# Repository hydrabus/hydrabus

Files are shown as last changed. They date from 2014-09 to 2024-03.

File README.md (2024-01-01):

HydraBus
========

HydraBus an open source multi-tool hardware

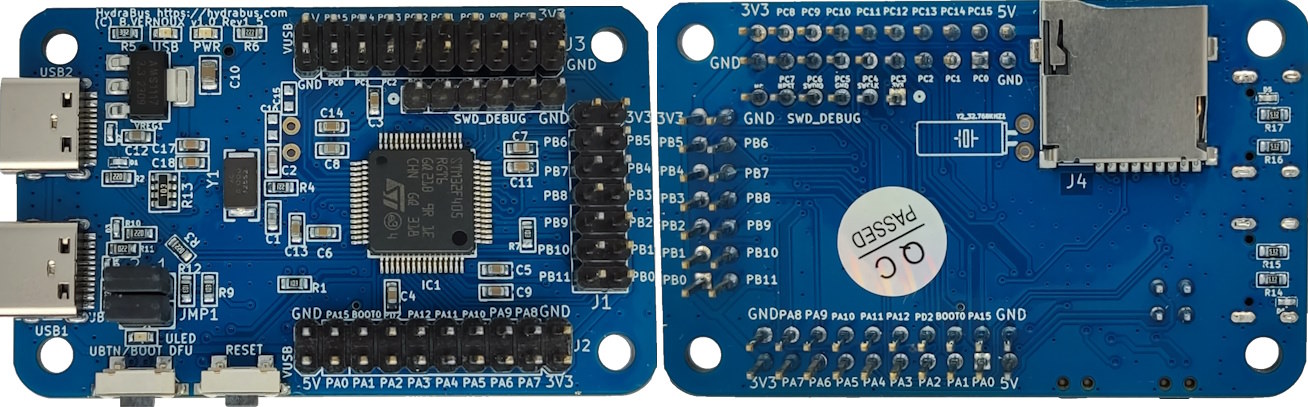
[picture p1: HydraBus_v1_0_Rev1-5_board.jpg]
HydraBus v1.0 Rev1.5 board


You can Buy HydraBus/HydraNFC Online: http://hydrabus.com/buy-online

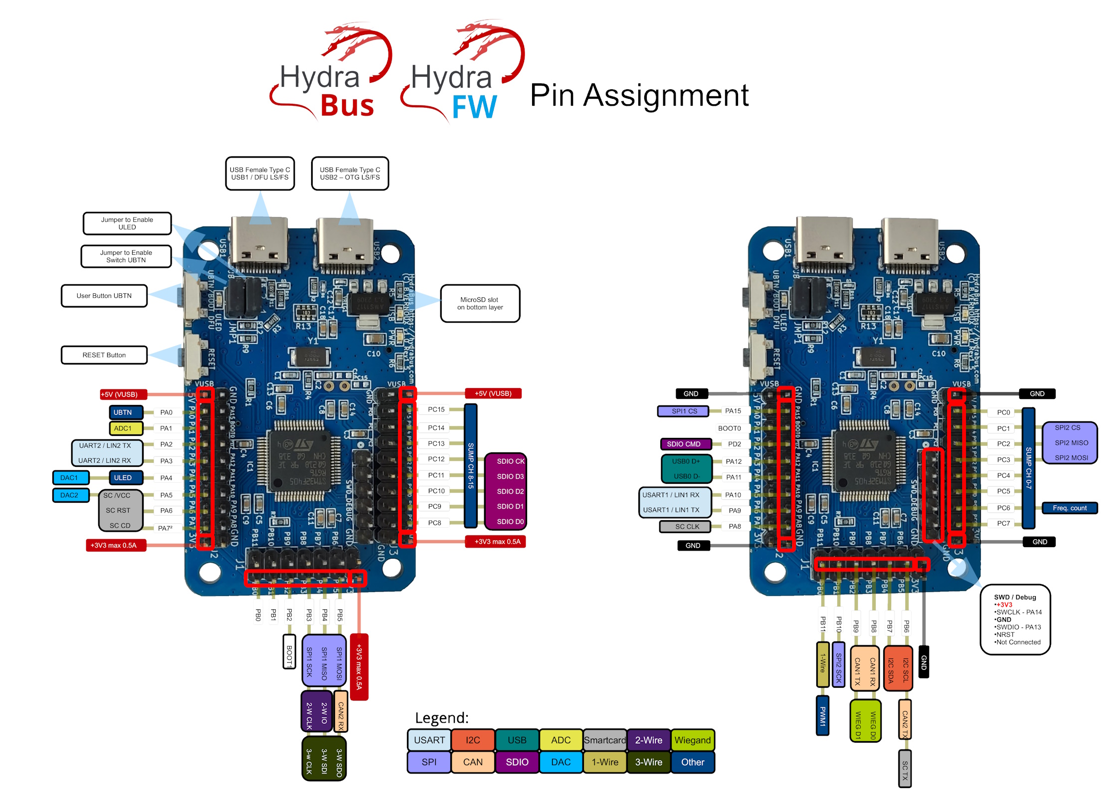
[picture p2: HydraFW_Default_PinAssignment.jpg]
HydraBus pins assignment


Wiki Getting Started: https://github.com/hydrabus/hydrafw/wiki/Getting-Started-with-HydraBus

HydraFW official firmware for Hydrabus
========

Wiki for HydraFW: https://github.com/hydrabus/hydrafw/wiki

See https://github.com/hydrabus/hydrafw

To build hydrafw see instructions here: 
* Windows: https://github.com/hydrabus/hydrafw/wiki/how-to-build-flash-and-use-hydrafw-on-windows
* Linux: https://github.com/hydrabus/hydrafw/wiki/how-to-build-flash-and-use-hydrafw-on-linux

Official Micro Python port for HydraBus
========
See https://github.com/micropython/micropython
Tested with GCC ARM 4.9 2015q3(GNU_ARM_4_9_2015q3) 
* See https://github.com/hydrabus/hydrafw_hydranfc_shield_v2/wiki `How to Build/Flash/Use HydraFW` for more details

To build micropython for HydraBus do:

    git clone --recursive https://github.com/micropython/micropython
    cd micropython/ports/stm32
    make BOARD=HYDRABUS

* At end of build you shall have:
 * GEN build-HYDRABUS/firmware.dfu
 * GEN build-HYDRABUS/firmware.hex
* In order to flash the *.dfu follow steps here: https://github.com/hydrabus/hydrafw/wiki/Getting-Started-with-HydraBus

For more details on official micropython hydrabus port see: https://github.com/micropython/micropython/tree/master/ports/stm32/boards/HYDRABUS

Official Black Magic JTAG/SWD debugger port for HydraBus
========
See https://github.com/blacksphere/blackmagic.git

Before to build the firmware check this issue (as you need a new GCC ARM Compiler >=4.9): https://github.com/blacksphere/blackmagic/issues/128
Tested with GCC ARM 4.9 2015q3(GNU_ARM_4_9_2015q3)
* See working version for reference blackmagic_branch_hydrabus_Firmware 1.5-00319-g49390fe-dirty.zip:
  * https://github.com/hydrabus/hydrabus/files/11436416/blackmagic_branch_hydrabus_Firmware.1.5-00319-g49390fe-dirty.zip
* Note: Latest version of blackmagic have "Device failed enumeration" issue see https://github.com/hydrabus/hydrabus/issues/4
* See https://github.com/hydrabus/hydrafw_hydranfc_shield_v2/wiki `How to Build/Flash/Use HydraFW` for more details

To build Black Magic for HydraBus do:

    git clone --recursive https://github.com/blacksphere/blackmagic.git
    cd blackmagic
    make PROBE_HOST=hydrabus

* At end of build you shall have:
 * OBJCOPY blackmagic.bin
 * OBJCOPY blackmagic.hex
 * Creating blackmagic.dfu
* In order to flash the *.dfu follow steps here: https://github.com/bvernoux/hydrafw/wiki/Getting-Started-with-HydraBus

For more details on official blackmagic hydrabus port see:
https://github.com/blacksphere/blackmagic/tree/master/src/platforms/hydrabus

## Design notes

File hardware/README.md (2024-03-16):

HydraBus Hardware
========

This directory contains HydraBus Hardware: 
Schematic, Board, Template
Case for HydraBus and documentations Pin Out.

For HydraBus_1_0_Shield_Template_Rev0 under Kicad see
* https://github.com/AnttiNykanen/hydrabus-shield-template-kicad

Licenses:
* HydraBus_1_0_Rev1_1 to HydraBus_1_0_Rev1_5: Hardware license [CC BY-NC 4.0](https://creativecommons.org/licenses/by-nc/4.0/) (for commercial license contact info@hydrabus.com)
* HydraBus_1_0_Rev1_SoBv1_DP6037 : Hardware license [Public Domain](http://unlicense.org)
* HydraBus_1_0_Shield_Template_Rev0: Hardware license [CC BY-SA 4.0](https://creativecommons.org/licenses/by-sa/4.0/)

You can buy online HydraBus: http://hydrabus.com/buy-online

For more details on the hardware see also http://hydrabus.com/hydrabus-1-0-hw-detailed/

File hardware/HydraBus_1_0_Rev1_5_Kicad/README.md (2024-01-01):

HydraBus Schematic and Board KiCad (6.0.11)
========

This directory contains HydraBus Schematic and Board for KiCad (6.0.11)

HydraBus: Hardware license [CC BY-NC 4.0](https://creativecommons.org/licenses/by-nc/4.0/) (for commercial license contact info@hydrabus.com)

For more details on the hardware see also http://hydrabus.com/hydrabus-1-0-specifications

Revision 1.5 (vs Rev 1.4)
- HydraBus v1 Rev1.5 is designed under KiCad 6.0.11
- Replaced 2x microUSB connectors by 2x USB Female Type C connectors (Korean Hroparts Elec TYPE-C-31-M-12)
- Replacement of ESD protections (as old ones are obsolete)

To summarize there is no any functional change between HydraBus v1 Rev1.5 and previous versions

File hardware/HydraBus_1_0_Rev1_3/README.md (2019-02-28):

HydraBus Schematic and Board CadSoft Eagle 6.x
========

This directory contains HydraBus Schematic and Board for CadSoft Eagle 6.x (free version works too)

HydraBus: Hardware license [CC BY-NC 4.0](https://creativecommons.org/licenses/by-nc/4.0/) (for commercial license contact info@hydrabus.com)

For more details on the hardware see also http://hydrabus.com/hydrabus-1-0-specifications

Revision 1.3 (vs Rev 1.2+)
- Modified the 2 microUSB to new ones which are more robust (HRO_U-F-M5DD-Y-L)
- Minor board routing improvement/optimization

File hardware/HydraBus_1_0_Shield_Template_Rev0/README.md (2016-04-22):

HydraBus 1_0 Shield Template CadSoft Eagle 6.x
========

This directory contains open source HydraBus 1_0 Shield Template Schematic and Board for CadSoft Eagle 6.x (free version works too)

HydraBus 1_0 Shield Template: Hardware licence CC BY-SA 4.0

For more details on the hardware see also http://hydrabus.com/?page_id=30

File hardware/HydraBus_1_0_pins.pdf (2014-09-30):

STM32F405RGT_pinName

Pin N° | Pin Name | Pin Type | 5V pin Tolerant | Functions | AF0 | AF1 | AF2 | AF3 | AF4 | AF5 | AF6 | AF7 | AF8 | AF9 | AF10 | AF11 | AF12 | AF13 | AF14 | AF15 | Default Function HydraBus
60 | BOOT0 | I | - | - | - | - | - | - | - | - | - | - | - | - | - | - | - | - | - | - | Default Boot from Flash (pull-down resistor 2.2Kohms)
7 | NRST | I/O | - | - | - | - | - | - | - | - | - | - | - | - | - | - | - | - | - | - | Reset Button / SWD_DEBUG
14 | PA0-WKUP (PA0) | I/O | YES | ADC123_IN0 / WKUP(4) | - | TIM2_CH1 TIM2_ETR | TIM 5_CH1 | TIM8_ETR | - | - | - | USART2_CTS | UART4_TX | - | - | ETH_MII_CRS | - | - | - | EVENTOUT | UBTN (User Button 0) Can be disabled by removing Jumper JMP1 UBTN
15 | PA1 | I/O | YES | ADC123_IN1 | - | TIM2_CH2 | TIM5_CH2 | - | - | - | - | USART2_RTS | UART4_RX | - | - | ETH_MII _RX_CLK ETH_RMII__REF_CLK | - | - | - | EVENTOUT | ADC123_IN1
16 | PA2 | I/O | YES | ADC123_IN2 | - | TIM2_CH3 | TIM5_CH3 | TIM9_CH1 | - | - | - | USART2_TX | - | - | - | ETH_MDIO | - | - | - | EVENTOUT | USART2_TX
17 | PA3 | I/O | YES | ADC123_IN3 | - | TIM2_CH4 | TIM5_CH4 | TIM9_CH2 | - | - | - | USART2_RX | - | - | OTG_HS_ULPI_D0 | ETH _MII_COL | - | - | - | EVENTOUT | USART2_RX
20 | PA4 | I/O | NO (3.3V) | ADC12_IN4 / DAC1_OUT | - | - | - | - | - | SPI1_NSS | SPI3_NSS I2S3_WS | USART2_CK | - | - | - | - | OTG_HS_SOF | DCMI_HSYNC | - | EVENTOUT | ULED (User LED 0) Can be disabled by removing Jumper JMP1 ULED
21 | PA5 | I/O | NO (3.3V) | ADC12_IN5 / DAC2_OUT | - | TIM2_CH1 TIM2_ETR | - | TIM8_CH1N | - | SPI1_SCK | - | - | - | - | OTG_HS_ULPI_CK | - | - | - | - | EVENTOUT | DAC2_OUT
22 | PA6 | I/O | YES | ADC12_IN6 | - | TIM1_BKIN | TIM3_CH1 | TIM8_BKIN | - | SPI1_MISO | - | - | - | TIM13_CH1 | - | - | - | DCMI_PIXCK | - | EVENTOUT | ADC12_IN6
23 | PA7 | I/O | YES | ADC12_IN7 | - | TIM1_CH1N | TIM3_CH2 | TIM8_CH1N | - | SPI1_MOSI | - | - | - | TIM14_CH1 | - | ETH_MII _RX_DV ETH_RMII _CRS_DV | - | - | - | EVENTOUT | ADC12_IN7
41 | PA8 | I/O | YES | | MCO1 | TIM1_CH1 | - | - | I2C3_SCL | - | - | USART1_CK | - | - | OTG_FS_SOF | - | - | - | - | EVENTOUT | USART1_CK
42 | PA9 | I/O | YES | OTG_FS_VBUS | - | TIM1_CH2 | - | - | I2C3_SMBA | - | - | USART1_TX | - | - | | - | - | DCMI_D0 | - | EVENTOUT | USART1_TX
43 | PA10 | I/O | YES | | - | TIM1_CH3 | - | - | | - | - | USART1_RX | - | - | OTG_FS_ID | - | - | DCMI_D1 | - | EVENTOUT | USART1_RX
44 | PA11 | I/O | YES | | - | TIM1_CH4 | - | - | | - | - | USART1_CTS | - | CAN1_RX | OTG_FS_DM | - | - | - | - | EVENTOUT | USB D-(USB0 connector)
45 | PA12 | I/O | YES | | - | TIM1_ETR | - | - | - | - | - | USART1_RTS | - | CAN1_TX | OTG_FS_DP | - | - | - | - | EVENTOUT | USB D+ (USB0 connector)
46 | PA13 (JTMS-SWDIO) | I/O | YES | | JTMS-SWDIO | - | - | - | - | - | - | - | - | - | - | - | - | - | - | EVENTOUT | SWDIO
49 | PA14 (JTCK-SWCLK) | I/O | YES | | TCK-SWCLK | - | - | - | - | - | - | - | - | - | - | - | - | - | - | EVENTOUT | SWCLK
50 | PA15 (JTDI) | I/O | YES | | JTDI | TIM 2_CH1 TIM 2_ETR | - | - | - | SPI1_NSS | SPI3_NSS/ I2S3S_WS | - | - | - | - | - | - | - | - | EVENTOUT | SPI1_NSS
26 | PB0 | I/O | YES | ADC12_IN8 | - | TIM1_CH2N | TIM3_CH3 | TIM8_CH2N | - | - | - | - | - | - | OTG_HS_ULPI_D1 | ETH _MII_RXD2 | - | - | - | EVENTOUT | ADC12_IN8
27 | PB1 | I/O | YES | ADC12_IN9 | - | TIM1_CH3N | TIM3_CH4 | TIM8_CH3N | - | - | - | - | - | - | OTG_HS_ULPI_D2 | ETH _MII_RXD3 | - | - | - | EVENTOUT | ADC12_IN9
28 | PB2-BOOT1 (PB2) | I/O | YES | | - | - | - | - | - | - | - | - | - | - | - | - | - | - | - | EVENTOUT
55 | PB3 (JTDO/ TRACESWO) | I/O | YES | | JTDO/ TRACESWO | TIM2_CH2 | - | - | - | SPI1_SCK | SPI3_SCK I2S3_CK | - | - | - | - | - | - | - | - | EVENTOUT | SPI1_SCK
56 | PB4 (NJTRST) | I/O | YES | | NJTRST | - | TIM3_CH1 | - | - | SPI1_MISO | SPI3_MISO | I2S3ext_SD | - | - | - | - | - | - | - | EVENTOUT | SPI1_MISO
57 | PB5 | I/O | YES | | - | - | TIM3_CH2 | - | I2C1_SMBA | SPI1_MOSI | SPI3_MOSI I2S3_SD | - | - | CAN2_RX | OTG_HS_ULPI_D7 | ETH _PPS_OUT | - | DCMI_D10 | - | EVENTOUT | SPI1_MOSI
58 | PB6 | I/O | YES | | - | - | TIM4_CH1 | - | I2C1_SCL | - | - | USART1_TX | - | CAN2_TX | - | - | - | DCMI_D5 | - | EVENTOUT | I2C1_SCL
59 | PB7 | I/O | YES | | - | - | TIM4_CH2 | - | I2C1_SDA | - | - | USART1_RX | - | - | - | - | FSMC_NL | DCMI_VSYNC | - | EVENTOUT | I2C1_SDA
61 | PB8 | I/O | YES | | - | - | TIM4_CH3 | TIM10_CH1 | I2C1_SCL | - | - | - | - | CAN1_RX | - | ETH _MII_TXD3 | SDIO_D4 | DCMI_D6 | - | EVENTOUT | CAN1_RX
62 | PB9 | I/O | YES | | - | - | TIM4_CH4 | TIM11_CH1 | I2C1_SDA | SPI2_NSS I2S2_WS | - | - | - | CAN1_TX | - | - | SDIO_D5 | DCMI_D7 | - | EVENTOUT | CAN1_TX
29 | PB10 | I/O | YES | | - | TIM2_CH3 | - | - | I2C2_SCL | SPI2_SCK I2S2_CK | - | USART3_TX | - | - | OTG_HS_ULPI_D3 | ETH_ MII_RX_ER | - | - | - | EVENTOUT | SPI2_SCK I2S2_CK
30 | PB11 | I/O | YES | | - | TIM2_CH4 | - | - | I2C2_SDA | - | - | USART3_RX | - | - | OTG_HS_ULPI_D4 | ETH _MII_TX_EN ETH _RMII_TX_EN | - | - | - | EVENTOUT
33 | PB12 | I/O | YES | | - | TIM1_BKIN | - | - | I2C2_SMBA | SPI2_NSS I2S2_WS | - | USART3_CK | - | CAN2_RX | OTG_HS_ULPI_D5 | ETH _MII_TXD0 ETH _RMII_TXD0 | OTG_HS_ID | - | - | EVENTOUT | USB ID (USB1 connector)
34 | PB13 | I/O | YES | OTG_HS_VBUS | - | TIM1_CH1N | - | - | - | SPI2_SCK I2S2_CK | - | USART3_CTS | - | CAN2_TX | OTG_HS_ULPI_D6 | ETH _MII_TXD1 ETH _RMII_TXD1 | - | - | - | EVENTOUT | Supply VUSB (USB1 connector)
35 | PB14 | I/O | YES | | - | TIM1_CH2N | - | TIM8_CH2N | - | SPI2_MISO | I2S2ext_SD | USART3_RTS | - | TIM12_CH1 | - | - | OTG_HS_DM | - | - | EVENTOUT | USB D-(USB1 connector)
36 | PB15 | I/O | YES | | RTC_50Hz | TIM1_CH3N | - | TIM8_CH3N | - | SPI2_MOSI I2S2_SD | - | - | - | TIM12_CH2 | - | - | OTG_HS_DP | - | - | EVENTOUT | USB D+ (USB1 connector)
8 | PC0 | I/O | YES | ADC123_IN10 | - | - | - | - | - | - | - | - | - | - | OTG_HS_ULPI_STP | - | - | - | - | EVENTOUT | ADC123_IN10
9 | PC1 | I/O | YES | ADC123_IN11 | - | - | - | - | - | - | - | - | - | - | - | ETH_MDC | - | - | - | EVENTOUT | SPI2 CS (by SW)
10 | PC2 | I/O | YES | ADC123_IN12 | - | - | - | - | - | SPI2_MISO | I2S2ext_SD | - | - | - | OTG_HS_ULPI_DIR | ETH _MII_TXD2 | - | - | - | EVENTOUT | SPI2_MISO
11 | PC3 | I/O | YES | ADC123_IN13 | - | - | - | - | - | SPI2_MOSI I2S2_SD | - | - | - | - | OTG_HS_ULPI_NXT | ETH _MII_TX_CLK | - | - | - | EVENTOUT | SPI2_MOSI
24 | PC4 | I/O | YES | ADC12_IN14 | - | - | - | - | - | - | - | - | - | - | - | ETH_MII_RXD0 ETH_RMII_RXD0 | - | - | - | EVENTOUT | ADC12_IN14
25 | PC5 | I/O | YES | ADC12_IN15 | - | - | - | - | - | - | - | - | - | - | - | ETH _MII_RXD1 ETH _RMII_RXD1 | - | - | - | EVENTOUT | ADC12_IN15
37 | PC6 | I/O | YES | | - | - | TIM3_CH1 | TIM8_CH1 | - | I2S2_MCK | - | - | USART6_TX | - | - | - | SDIO_D6 | DCMI_D0 | - | EVENTOUT | USART6_TX
38 | PC7 | I/O | YES | | - | - | TIM3_CH2 | TIM8_CH2 | | | I2S3_MCK | | USART6_RX | | | | SDIO_D7 | DCMI_D1 | | EVENTOUT | USART6_RX
39 | PC8 | I/O | YES | | - | - | TIM3_CH3 | TIM8_CH3 | | | | | USART6_CK | | | | SDIO_D0 | DCMI_D2 | | EVENTOUT | MicroSD Card SD 4bits SDIO_D0
40 | PC9 | I/O | YES | | MCO2 | - | TIM3_CH4 | TIM8_CH4 | I2C3_SDA | I2S_CKIN | | | | | | | SDIO_D1 | DCMI_D3 | | EVENTOUT | MicroSD Card SD 4bits SDIO_D1
51 | PC10 | I/O | YES | | - | - | - | - | - | - | SPI3_SCK/ I2S3S_CK | USART3_TX/ | UART4_TX | - | - | - | SDIO_D2 | DCMI_D8 | - | EVENTOUT | MicroSD Card SD 4bits SDIO_D2
52 | PC11 | I/O | YES | | - | - | - | - | - | I2S3ext_SD | SPI3_MISO/ | USART3_RX | UART4_RX | - | - | - | SDIO_D3 | DCMI_D4 | - | EVENTOUT | MicroSD Card SD 4bits SDIO_D3
53 | PC12 | I/O | YES | | - | - | - | - | - | - | SPI3_MOSI I2S3_SD | USART3_CK | UART5_TX | - | - | - | SDIO_CK | DCMI_D9 | - | EVENTOUT | MicroSD Card SD 4bits SDIO_CK
2 | PC13 | I/O | YES | EVENTOUT / RTC_AF1 | - | - | - | - | - | - | - | - | - | - | - | - | - | - | - | -
3 | PC14-OSC32_IN (PC14) | I/O | YES | EVENTOUT / OSC32_IN(4) | - | - | - | - | - | - | - | - | - | - | - | - | - | - | - | - | Optional RTC 32,768KHz
4 | PC15-OSC32_OUT (PC15) | I/O | YES | EVENTOUT / OSC32_OUT(4) | - | - | - | - | - | - | - | - | - | - | - | - | - | - | - | - | Optional RTC 32,768KHz
54 | PD2 | I/O | YES | | - | - | TIM3_ETR | - | - | - | - | - | UART5_RX | - | - | - | SDIO_CMD | DCMI_D11 | - | EVENTOUT | MicroSD Card SD 4bits SDIO_CMD
5 | PH0-OSC_IN (PH0) | I/O | YES | EVENTOUT / OSC_IN(4) | - | - | - | - | - | - | - | - | - | - | - | - | - | - | - | - | Quartz 8MHz
6 | PH1-OSC_OUT (PH1) | I/O | YES | EVENTOUT / OSC_OUT(4) | - | - | - | - | - | - | - | - | - | - | - | - | - | - | - | - | Quartz 8MHz
1 | VBAT | - | - | - | - | - | - | - | - | - | - | - | - | - | - | - | - | - | - | - | +3V3
31 | VCAP_1 | - | - | - | - | - | - | - | - | - | - | - | - | - | - | - | - | - | - | - | -
47 | VCAP_2 | - | - | - | - | - | - | - | - | - | - | - | - | - | - | - | - | - | - | - | -
19 | VDD | - | - | - | - | - | - | - | - | - | - | - | - | - | - | - | - | - | - | - | -
32 | VDD | - | - | - | - | - | - | - | - | - | - | - | - | - | - | - | - | - | - | - | -
48 | VDD | - | - | - | - | - | - | - | - | - | - | - | - | - | - | - | - | - | - | - | -
64 | VDD | - | - | - | - | - | - | - | - | - | - | - | - | - | - | - | - | - | - | - | -
13 | VDDA | - | - | - | - | - | - | - | - | - | - | - | - | - | - | - | - | - | - | - | -
18 | VSS | - | - | - | - | - | - | - | - | - | - | - | - | - | - | - | - | - | - | - | -
63 | VSS | - | - | - | - | - | - | - | - | - | - | - | - | - | - | - | - | - | - | - | -
12 | VSSA | - | - | - | - | - | - | - | - | - | - | - | - | - | - | - | - | - | - | - | -

Pin 3.3V Only !! Not 5V tolerant
HydraBus pins not reusable
HydraBus pins can be reused, available on J1/J2/J3 or SWD_DEBUG
Default Peripheral for HydraBus HydraFW

STM32F405RGT_pinNo

Pin N° | Pin Name | Pin Type | 5V pin Tolerant | Functions | AF0 | AF1 | AF2 | AF3 | AF4 | AF5 | AF6 | AF7 | AF8 | AF9 | AF10 | AF11 | AF12 | AF13 | AF14 | AF15 | Default Function HydraBus
1 | VBAT | - | - | - | - | - | - | - | - | - | - | - | - | - | - | - | - | - | - | - | +3V3
2 | PC13 | I/O | YES | EVENTOUT / RTC_AF1 | - | - | - | - | - | - | - | - | - | - | - | - | - | - | - | -
3 | PC14-OSC32_IN (PC14) | I/O | YES | EVENTOUT / OSC32_IN(4) | - | - | - | - | - | - | - | - | - | - | - | - | - | - | - | - | Optional RTC 32,768KHz
4 | PC15-OSC32_OUT (PC15) | I/O | YES | EVENTOUT / OSC32_OUT(4) | - | - | - | - | - | - | - | - | - | - | - | - | - | - | - | - | Optional RTC 32,768KHz
5 | PH0-OSC_IN (PH0) | I/O | YES | EVENTOUT / OSC_IN(4) | - | - | - | - | - | - | - | - | - | - | - | - | - | - | - | - | Quartz 8MHz
6 | PH1-OSC_OUT (PH1) | I/O | YES | EVENTOUT / OSC_OUT(4) | - | - | - | - | - | - | - | - | - | - | - | - | - | - | - | - | Quartz 8MHz
7 | NRST | I/O | - | - | - | - | - | - | - | - | - | - | - | - | - | - | - | - | - | - | Reset Button / SWD_DEBUG
8 | PC0 | I/O | YES | ADC123_IN10 | - | - | - | - | - | - | - | - | - | - | OTG_HS_ULPI_STP | - | - | - | - | EVENTOUT
9 | PC1 | I/O | YES | ADC123_IN11 | - | - | - | - | - | - | - | - | - | - | - | ETH_MDC | - | - | - | EVENTOUT
10 | PC2 | I/O | YES | ADC123_IN12 | - | - | - | - | - | SPI2_MISO | I2S2ext_SD | - | - | - | OTG_HS_ULPI_DIR | ETH _MII_TXD2 | - | - | - | EVENTOUT
11 | PC3 | I/O | YES | ADC123_IN13 | - | - | - | - | - | SPI2_MOSI I2S2_SD | - | - | - | - | OTG_HS_ULPI_NXT | ETH _MII_TX_CLK | - | - | - | EVENTOUT
12 | VSSA | - | - | - | - | - | - | - | - | - | - | - | - | - | - | - | - | - | - | - | -
13 | VDDA | - | - | - | - | - | - | - | - | - | - | - | - | - | - | - | - | - | - | - | -
14 | PA0-WKUP (PA0) | I/O | YES | ADC123_IN0 / WKUP(4) | - | TIM2_CH1 TIM2_ETR | TIM 5_CH1 | TIM8_ETR | - | - | - | USART2_CTS | UART4_TX | - | - | ETH_MII_CRS | - | - | - | EVENTOUT | UBTN (User Button 0) Can be disabled by removing Jumper JMP1 UBTN
15 | PA1 | I/O | YES | ADC123_IN1 | - | TIM2_CH2 | TIM5_CH2 | - | - | - | - | USART2_RTS | UART4_RX | - | - | ETH_MII _RX_CLK ETH_RMII__REF_ CLK | - | - | - | EVENTOUT
16 | PA2 | I/O | YES | ADC123_IN2 | - | TIM2_CH3 | TIM5_CH3 | TIM9_CH1 | - | - | - | USART2_TX | - | - | - | ETH_MDIO | - | - | - | EVENTOUT
17 | PA3 | I/O | YES | ADC123_IN3 | - | TIM2_CH4 | TIM5_CH4 | TIM9_CH2 | - | - | - | USART2_RX | - | - | OTG_HS_ULPI_D0 | ETH _MII_COL | - | - | - | EVENTOUT
18 | VSS | - | - | - | - | - | - | - | - | - | - | - | - | - | - | - | - | - | - | - | -
19 | VDD | - | - | - | - | - | - | - | - | - | - | - | - | - | - | - | - | - | - | - | -
20 | PA4 | I/O | NO (3.3V) | ADC12_IN4 / DAC1_OUT | - | - | - | - | - | SPI1_NSS | SPI3_NSS I2S3_WS | USART2_CK | - | - | - | - | OTG_HS_SOF | DCMI_HSYNC | - | EVENTOUT | ULED (User LED 0) Can be disabled by removing Jumper JMP1 ULED
21 | PA5 | I/O | NO (3.3V) | ADC12_IN5 / DAC2_OUT | - | TIM2_CH1 TIM2_ETR | - | TIM8_CH1N | - | SPI1_SCK | - | - | - | - | OTG_HS_ULPI_CK | - | - | - | - | EVENTOUT
22 | PA6 | I/O | YES | ADC12_IN6 | - | TIM1_BKIN | TIM3_CH1 | TIM8_BKIN | - | SPI1_MISO | - | - | - | TIM13_CH1 | - | - | - | DCMI_PIXCK | - | EVENTOUT
23 | PA7 | I/O | YES | ADC12_IN7 | - | TIM1_CH1N | TIM3_CH2 | TIM8_CH1N | - | SPI1_MOSI | - | - | - | TIM14_CH1 | - | ETH_MII _RX_DV ETH_RMII _CRS_DV | - | - | - | EVENTOUT
24 | PC4 | I/O | YES | ADC12_IN14 | - | - | - | - | - | - | - | - | - | - | - | ETH_MII_RXD0 ETH_RMII_RXD0 | - | - | - | EVENTOUT
25 | PC5 | I/O | YES | ADC12_IN15 | - | - | - | - | - | - | - | - | - | - | - | ETH _MII_RXD1 ETH _RMII_RXD1 | - | - | - | EVENTOUT
26 | PB0 | I/O | YES | ADC12_IN8 | - | TIM1_CH2N | TIM3_CH3 | TIM8_CH2N | - | - | - | - | - | - | OTG_HS_ULPI_D1 | ETH _MII_RXD2 | - | - | - | EVENTOUT
27 | PB1 | I/O | YES | ADC12_IN9 | - | TIM1_CH3N | TIM3_CH4 | TIM8_CH3N | - | - | - | - | - | - | OTG_HS_ULPI_D2 | ETH _MII_RXD3 | - | - | - | EVENTOUT
28 | PB2-BOOT1 (PB2) | I/O | YES | | - | - | - | - | - | - | - | - | - | - | - | - | - | - | - | EVENTOUT
29 | PB10 | I/O | YES | | - | TIM2_CH3 | - | - | I2C2_SCL | SPI2_SCK I2S2_CK | - | USART3_TX | - | - | OTG_HS_ULPI_D3 | ETH_ MII_RX_ER | - | - | - | EVENTOUT
30 | PB11 | I/O | YES | | - | TIM2_CH4 | - | - | I2C2_SDA | - | - | USART3_RX | - | - | OTG_HS_ULPI_D4 | ETH _MII_TX_EN ETH _RMII_TX_EN | - | - | - | EVENTOUT
31 | VCAP_1 | - | - | - | - | - | - | - | - | - | - | - | - | - | - | - | - | - | - | - | -
32 | VDD | - | - | - | - | - | - | - | - | - | - | - | - | - | - | - | - | - | - | - | -
33 | PB12 | I/O | YES | | - | TIM1_BKIN | - | - | I2C2_SMBA | SPI2_NSS I2S2_WS | - | USART3_CK | - | CAN2_RX | OTG_HS_ULPI_D5 | ETH _MII_TXD0 ETH _RMII_TXD0 | OTG_HS_ID | - | - | EVENTOUT | USB ID (USB1 connector)
34 | PB13 | I/O | YES | OTG_HS_VBUS | - | TIM1_CH1N | - | - | - | SPI2_SCK I2S2_CK | - | USART3_CTS | - | CAN2_TX | OTG_HS_ULPI_D6 | ETH _MII_TXD1 ETH _RMII_TXD1 | - | - | - | EVENTOUT | Supply VUSB (USB1 connector)
35 | PB14 | I/O | YES | | - | TIM1_CH2N | - | TIM8_CH2N | - | SPI2_MISO | I2S2ext_SD | USART3_RTS | - | TIM12_CH1 | - | - | OTG_HS_DM | - | - | EVENTOUT | USB D-(USB1 connector)
36 | PB15 | I/O | YES | | RTC_50Hz | TIM1_CH3N | - | TIM8_CH3N | - | SPI2_MOSI I2S2_SD | - | - | - | TIM12_CH2 | - | - | OTG_HS_DP | - | - | EVENTOUT | USB D+ (USB1 connector)
37 | PC6 | I/O | YES | | - | - | TIM3_CH1 | TIM8_CH1 | - | I2S2_MCK | - | - | USART6_TX | - | - | - | SDIO_D6 | DCMI_D0 | - | EVENTOUT
38 | PC7 | I/O | YES | | - | - | TIM3_CH2 | TIM8_CH2 | | | I2S3_MCK | | USART6_RX | | | | SDIO_D7 | DCMI_D1 | | EVENTOUT
39 | PC8 | I/O | YES | | - | - | TIM3_CH3 | TIM8_CH3 | | | | | USART6_CK | | | | SDIO_D0 | DCMI_D2 | | EVENTOUT | MicroSD Card SD 4bits SDIO_D0
40 | PC9 | I/O | YES | | MCO2 | - | TIM3_CH4 | TIM8_CH4 | I2C3_SDA | I2S_CKIN | | | | | | | SDIO_D1 | DCMI_D3 | | EVENTOUT | MicroSD Card SD 4bits SDIO_D1
41 | PA8 | I/O | YES | | MCO1 | TIM1_CH1 | - | - | I2C3_SCL | - | - | USART1_CK | - | - | OTG_FS_SOF | - | - | - | - | EVENTOUT
42 | PA9 | I/O | YES | OTG_FS_VBUS | - | TIM1_CH2 | - | - | I2C3_SMBA | - | - | USART1_TX | - | - | | - | - | DCMI_D0 | - | EVENTOUT
43 | PA10 | I/O | YES | | - | TIM1_CH3 | - | - | | - | - | USART1_RX | - | - | OTG_FS_ID | - | - | DCMI_D1 | - | EVENTOUT
44 | PA11 | I/O | YES | | - | TIM1_CH4 | - | - | | - | - | USART1_CTS | - | CAN1_RX | OTG_FS_DM | - | - | - | - | EVENTOUT | USB D-(USB0 connector)
45 | PA12 | I/O | YES | | - | TIM1_ETR | - | - | - | - | - | USART1_RTS | - | CAN1_TX | OTG_FS_DP | - | - | - | - | EVENTOUT | USB D+ (USB0 connector)
46 | PA13 (JTMS-SWDIO) | I/O | YES | | JTMS-SWDIO | - | - | - | - | - | - | - | - | - | - | - | - | - | - | EVENTOUT | SWDIO
47 | VCAP_2 | - | - | - | - | - | - | - | - | - | - | - | - | - | - | - | - | - | - | - | -
48 | VDD | - | - | - | - | - | - | - | - | - | - | - | - | - | - | - | - | - | - | - | -
49 | PA14 (JTCK-SWCLK) | I/O | YES | | TCK-SWCLK | - | - | - | - | - | - | - | - | - | - | - | - | - | - | EVENTOUT | SWCLK
50 | PA15 (JTDI) | I/O | YES | | JTDI | TIM 2_CH1 TIM 2_ETR | - | - | - | SPI1_NSS | SPI3_NSS/ I2S3S_WS | - | - | - | - | - | - | - | - | EVENTOUT
51 | PC10 | I/O | YES | | - | - | - | - | - | - | SPI3_SCK/ I2S3S_CK | USART3_TX/ | UART4_TX | - | - | - | SDIO_D2 | DCMI_D8 | - | EVENTOUT | MicroSD Card SD 4bits SDIO_D2
52 | PC11 | I/O | YES | | - | - | - | - | - | I2S3ext_SD | SPI3_MISO/ | USART3_RX | UART4_RX | - | - | - | SDIO_D3 | DCMI_D4 | - | EVENTOUT | MicroSD Card SD 4bits SDIO_D3
53 | PC12 | I/O | YES | | - | - | - | - | - | - | SPI3_MOSI I2S3_SD | USART3_CK | UART5_TX | - | - | - | SDIO_CK | DCMI_D9 | - | EVENTOUT | MicroSD Card SD 4bits SDIO_CK
54 | PD2 | I/O | YES | | - | - | TIM3_ETR | - | - | - | - | - | UART5_RX | - | - | - | SDIO_CMD | DCMI_D11 | - | EVENTOUT | MicroSD Card SD 4bits SDIO_CMD
55 | PB3 (JTDO/ TRACESWO) | I/O | YES | | JTDO/ TRACESWO | TIM2_CH2 | - | - | - | SPI1_SCK | SPI3_SCK I2S3_CK | - | - | - | - | - | - | - | - | EVENTOUT
56 | PB4 (NJTRST) | I/O | YES | | NJTRST | - | TIM3_CH1 | - | - | SPI1_MISO | SPI3_MISO | I2S3ext_SD | - | - | - | - | - | - | - | EVENTOUT
57 | PB5 | I/O | YES | | - | - | TIM3_CH2 | - | I2C1_SMBA | SPI1_MOSI | SPI3_MOSI I2S3_SD | - | - | CAN2_RX | OTG_HS_ULPI_D7 | ETH _PPS_OUT | - | DCMI_D10 | - | EVENTOUT
58 | PB6 | I/O | YES | | - | - | TIM4_CH1 | - | I2C1_SCL | - | - | USART1_TX | - | CAN2_TX | - | - | - | DCMI_D5 | - | EVENTOUT
59 | PB7 | I/O | YES | | - | - | TIM4_CH2 | - | I2C1_SDA | - | - | USART1_RX | - | - | - | - | FSMC_NL | DCMI_VSYNC | - | EVENTOUT
60 | BOOT0 | I | - | - | - | - | - | - | - | - | - | - | - | - | - | - | - | - | - | - | Default Boot from Flash (pull-down resistor 2.2Kohms)
61 | PB8 | I/O | YES | | - | - | TIM4_CH3 | TIM10_CH1 | I2C1_SCL | - | - | - | - | CAN1_RX | - | ETH _MII_TXD3 | SDIO_D4 | DCMI_D6 | - | EVENTOUT
62 | PB9 | I/O | YES | | - | - | TIM4_CH4 | TIM11_CH1 | I2C1_SDA | SPI2_NSS I2S2_WS | - | - | - | CAN1_TX | - | - | SDIO_D5 | DCMI_D7 | - | EVENTOUT
63 | VSS | - | - | - | - | - | - | - | - | - | - | - | - | - | - | - | - | - | - | - | -
64 | VDD | - | - | - | - | - | - | - | - | - | - | - | - | - | - | - | - | - | - | - | -

Pin 3.3V Only !! Not 5V tolerant
HydraBus pins not reusable

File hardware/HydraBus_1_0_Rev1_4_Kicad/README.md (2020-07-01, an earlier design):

HydraBus Schematic and Board KiCad (5.1.5)-2
========

This directory contains HydraBus Schematic and Board for KiCad (5.1.5)-2

HydraBus: Hardware license [CC BY-NC 4.0](https://creativecommons.org/licenses/by-nc/4.0/) (for commercial license contact info@hydrabus.com)

For more details on the hardware see also http://hydrabus.com/hydrabus-1-0-specifications

Revision 1.4 (vs Rev 1.3)
- The BOM is optimized to find/buy most of the parts on lcsc.com
- HydraBus v1 Rev1.4 is fully designed under KiCad 5.1.5-2 (Latest official stable release), before it was designed with Eagle 6.x
- 8MHz Crystal Y1 has been replaced by a SMD part (Yangxing Tech X50328MSB2GI) on top side of the PCB with better performances
  - Frequency Tolerance @25°C X50328MSB2GI +/-10ppm vs FOXSLF/080-20 +/-30ppm.
  - Operating Temperature X50328MSB2GI -40°C / +85°C vs FOXSLF/080-20 -20°C / +70°C.
- Capacitors C1 & C2 for the 8MHz Crystal are changed to 18pF (before it was 27pF) to prevent some USB issues on some board which does not work correctly with STM32F405 USB DFU (embedded in ROM).
- Decoupling capacitors (100nF replaced by 220nF, 1uF replaced by 2.2uF) are modified to use less references with higher value which also reduce the noise.
- microSD connector part replaced by compatible part HOAUC HYC77-TF09-200UBTN/BOOT DFU and RESET switch replaced by compatible part HYP (Hongyuan Precision) 1TS002G-2700-3500-CT.

To summarize there is no any functional change between HydraBus v1 Rev1.4 and previous versions

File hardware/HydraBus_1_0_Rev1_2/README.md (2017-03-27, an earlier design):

HydraBus Schematic and Board CadSoft Eagle 7.x
========

This directory contains HydraBus Schematic and Board for CadSoft Eagle 7.1 or more (free version works too)

HydraBus: Hardware license [CC BY-NC 4.0](https://creativecommons.org/licenses/by-nc/4.0/) (for commercial license contact info@hydrabus.com)

For more details on the hardware see also http://hydrabus.com/hydrabus-1-0-specifications/

V1.0 Revision 1.2 (Fully Compatible with Previous Board V1.0 Rev1.1):
  * Labels on both sides of the PCB with GPIO names (PBx, PCx ...).
  * Added R7 10K on PB2, BOOT0 is connected to JMP1-2 for easier BOOT USB DFU.
    * BOOT USB DFU (do not require any wire):
      1. Press UBTN button then Press RESET button
      2. Keep pressing UBTN then Release RESET
      3. Wait 1s then Release UBTN

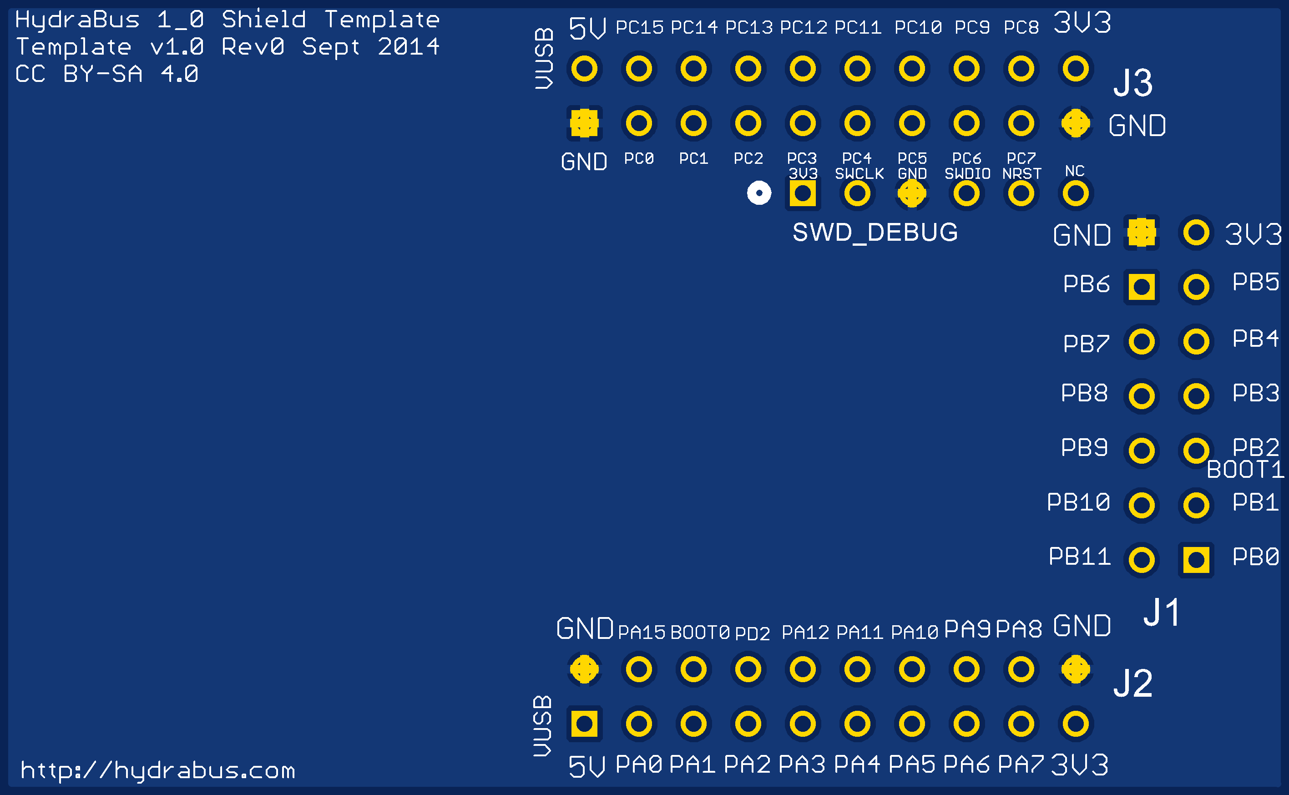
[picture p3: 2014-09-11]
hardware/HydraBus_1_0_Shield_Template_Rev0/HydraBus_1_0_Shield_Template_Rev0_board_top.png

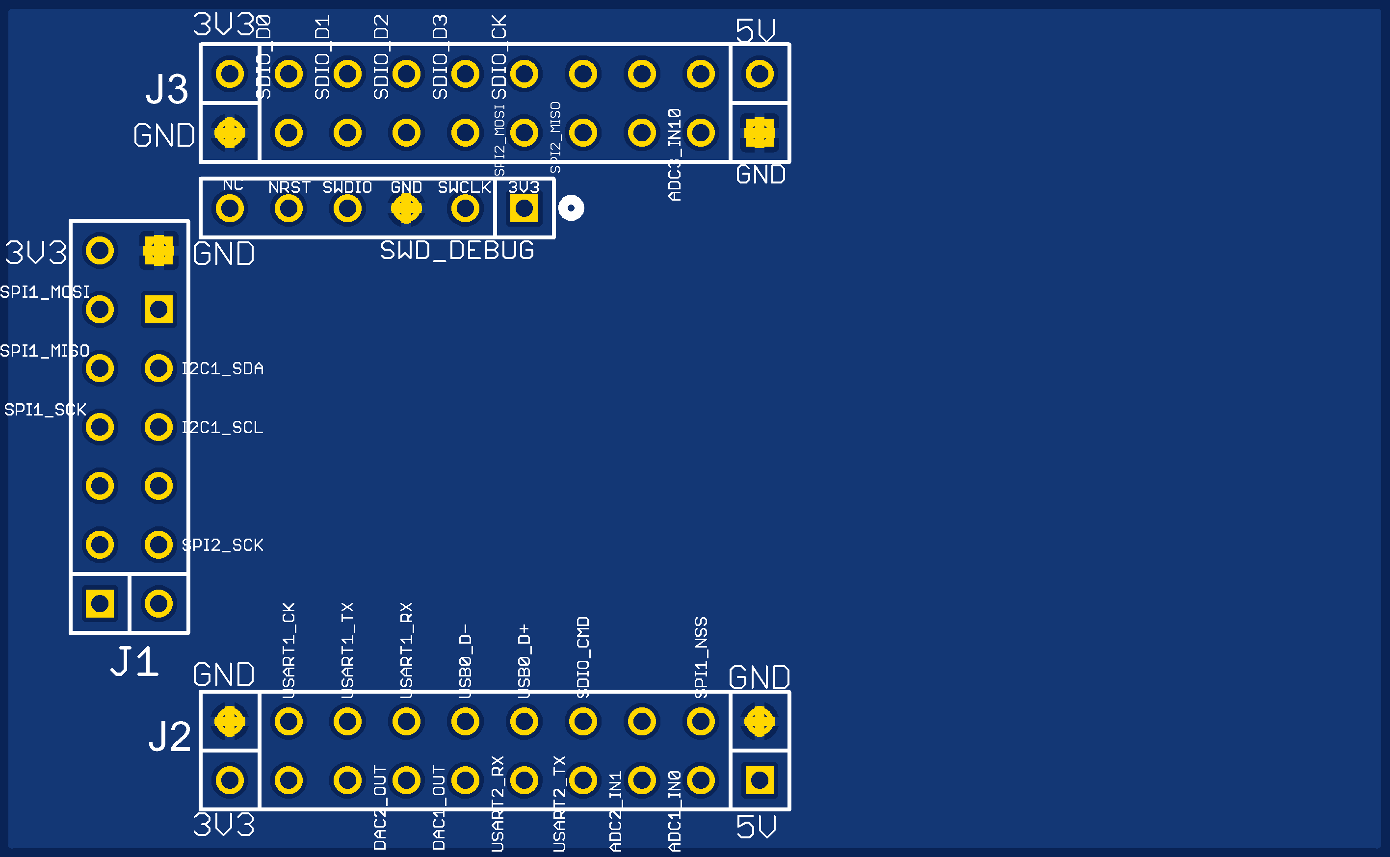
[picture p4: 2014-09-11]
hardware/HydraBus_1_0_Shield_Template_Rev0/HydraBus_1_0_Shield_Template_Rev0_board_bottom.png

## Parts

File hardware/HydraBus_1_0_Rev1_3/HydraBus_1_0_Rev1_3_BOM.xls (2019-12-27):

Qty | Value | Device | Package | Parts | Description | OPL_REF | DigiKey Ref | Mouser Ref | OPL SKU | MPN | Short Description
2 | SHORT-JUMPER-2P-3460440P1 | SHORT-JUMPER-2P-3460440P1 | 2P-2.54 | UBTN, ULED (JMP1) |  | DIP Black Jumper;2P-2.54 |  |  | 320190003 | - | CONN JUMPER SHORTING
1 | CON_HEADER_1X06-PTH | CON_HEADER_1X06-PTH | M1X6 | SWD_DEBUG | 1x6 pin header 2.54mm lengthen male. | - | S1022EC-06-ND |  | - | PREC006SABN-RC | CONN HEADER .100" SNGL STR 6POS (Head Dim=5.84mm, Tail Dim=5.84mm)
1 | CON_HEADER_2X07PTH | CON_HEADER_2X07PTH | M2X7 | J1 | 2x7 pin header 2.54mm lengthen male. | - | S2222EC-29-ND |  | - | PREC029DFBN-RC | Sullins Connector Solutions S2222EC-29-ND 2x29 pins, requires to cut like defined hereafter: 2x2 (JMP1) + 2x7 (J1) + 2x10 (J2) + 2x10 (J3) CONN HEADER .100" DUAL STR 58POS Male Pin 2.54mm Through Hole (Head Dim=8.08mm, Tail Dim=5.59mm)
2 | CON_HEADER_2X10 | CON_HEADER_2X10 | M2X10 | J2, J3, JMP1 | J2 & J3 2x10 pin header 2.54mm lengthen male.
3 | - | LED | LED0603 | PWR, ULED, USB | LED | 19-217-G7C-AN1P2-3T SMD LED Clear-Green |  | 720-LGQ971-KN-1 | 304090043 | 19-217-G7C-AN1P2-3T | SMD LED Clear-Green
1 | Micro SD Card Socket | Micro SD Card Socket | 9P-SMD-W/-RING | J4 | Micro SD Card Socket | ST-TF-003A Micro SD Card Socket |  |  | 320090000 | ST-TF-003A | Micro SD Card Socket
2 | BUTTON-2P-REINFORCE-3100060P1 | BUTTON-2P-REINFORCE-3100060P1 | 4P-SMD-7.0X3.5X3.5H-90D | UBTN, RESET |  | TS-1188E 4P-SMD-7.0X3.5X3.5H-90D |  |  | 311020023 | TS-1188E | SMD Button
2 | MICRO-USB | MICRO-USB-HRO_U-F-M5DD-Y-L | HRO_U-F-M5DD-Y-L | USB1, USB2 |  | U-F-M5DD-Y-L |  | - | - | U-F-M5DD-Y-L | MICRO USB ShenZhen OPL
1 | 631-1010-1-ND | OSC-XTAL-HC-49U-PTH | HC-49U-PTH | Y1_8MHZ |  | - | 631-1100-ND | 559-FOXS080-20-LF | - | FOXSLF/080-20 | Crystals 8MHz 20pF
2 | 27pF | C-0603 | C0603 | C1, C2 | CAPACITOR, European symbol | CC0603JRNPO9BN270 SMD CAP Ceramic 27pF-50V-5%-NPO |  | 77-VJ0603A270JXACBC | 302010142 | CC0603JRNPO9BN270 | SMD CAP Ceramic 27pF-50V-5%-NPO
8 | 100nF | C-0603 | C0603 | C3, C4, C5, C6, C7, C8, C12, C18 | CAPACITOR, European symbol | CC0603KRX7R9BB104 SMD CAP Ceramic 100nF-50V-10%-X7R |  | 603-C0603KPX7R7BB104 | 302010138 | CC0603KRX7R9BB104 | SMD CAP Ceramic 100nF-50V-10%-X7R
2 | 2.2uF | C-EUC0603 | C0603@1 | C9, C11 | CAPACITOR, European symbol | CC0603KRX7R6BB225 SMD CAP Ceramic 2.2uF-10V-10%-X7R | 587-1254-1-ND | 963-JMK107BJ225KA-T | 302010054 | JMK107BJ225KA-T | CAP CER 2.2UF 6.3V 10% X5R 0603
2 | 1uF | C-0603 | C0603 | C13, C17 | CAPACITOR, European symbol | CC0603KRX7R8BB105 SMD CAP Ceramic 1uF-25V-10%-X7R |  | 77-VJ0603V105MXQPBC | 302010139 | CC0603KRX7R8BB105 | SMD CAP Ceramic 1uF-25V-10%-X7R
1 | 4.7uF | C-EUC0603 | C0603@1 | C14 | CAPACITOR, European symbol | CC0603KRX5R6BB475 SMD CAP Ceramic 4.7uF-10V-10%-X5R | 490-5421-1-ND | 81-GRM188R60J475ME9D | 302010111 | GRM188R60J475ME19D | CAP CER 4.7UF 6.3V 20% X5R 0603
1 | 10uF | C-0805 | C0805 | C10 | CAPACITOR, European symbol | CC0805KKX5R8BB106 SMD CAP Ceramic 10uF-25V-10%-X5R |  | 581-08056D106MAT2A | 302010178 | CC0805KKX5R8BB106 | SMD CAP Ceramic 10uF-25V-10%-X5R
4 | 22 | R-0603 | R0603 | R2, R3, R10, R11 | RESISTOR, European symbol | RC0603JR-0722RL SMD RES 22R-5%-1/10W |  | 71-CRCW0603-22-E3 | 301010289 | RC0603JR-0722RL
1 | 220 | R-EU_R0603 | R0603@1 | R4 | RESISTOR, European symbol | RC0603JR-07220RL SMD RES 220R-5%-1/10W | 541-220HCT-ND | 71-CRCW0603-220-E3 | 301010163 | RC0603JR-07220RL | RES 220 OHM 1/10W 1% 0603 SMD
1 | 3.3K | R-EU_R0603 | R0603@1 | R5 | RESISTOR, European symbol | RC0603FR-073K3L SMD RES 3.3K-1%-1/10W;0603 | 541-3.30KHCT-ND | 71-CRCW0603-3.3K-E3 | 301010251 | RC0603FR-073K3L | RES 3.30K OHM 1/10W 1% 0603 SMD
2 | 2.2K | R-EU_R0603 | R0603@1 | R6, R8 | RESISTOR, European symbol | RC0603JR-072K2L SMD RES 2.2K-5%-1/10W | 541-2.20KHCT-ND | 71-CRCW0603-2.2K-E3 | 301010124 | RC0603JR-072K2L | RES 2.20K OHM 1/10W 1% 0603 SMD
4 | 10K | R-0603 | R0603 | R1, R7, R9, R12 | RESISTOR, European symbol | RC0603JR-0710KL SMD RES 10K-5%-1/10W |  | 667-ERJ-3GEYJ103V | 301010293 | RC0603JR-0710KL | SMD RES 10K-5%-1/10W
1 | 10K | R1206-8 | R1206-8 | R13 | Resistor Array | - | YC164J-10KCT-ND | 603-YC164-JR-0710KL | - | YC164-JR-0710KL | SMD RES ARRAY 10K OHM 4 RES 1206
1 | IP4220CZ6 | IP4220CZ6 | 6-TSOP | U1 | IC USB DUAL ESD PROTECT 6TSOP | IP4220CZ6,125 | 568-3529-1-ND | 771-IP4220CZ6-T/R | - | IP4220CZ6,125 | IC USB DUAL ESD PROTECT 6TSOP
1 | LD1117AS33TR | LD117AS33TR | SOT223 | VREG1 | Low drop fixed positive voltage Regulators 1 A | CJT1117-3.3 SMD PMIC; LDO;Vin 5V;3.3V;1A;Without En;1-Ch |  | 511-LD1117AS33 | 310030097 | CJT1117-3.3 | 1A LOW DROPOUT LINEAR REGULATOR 3.3V
1 | STM32F405RGT | STM32F405RGT | LQFP64 | IC1 | STM32F405R*T | - | 497-11767-ND | 511-STM32F405RGT6 | - | STM32F405RGT6 | IC MCU 32BIT 1MB FLASH 64LQFP
BLUE = Seeed Studio Open Part Library (OPL) http://www.seeedstudio.com/wiki/Open_parts_library
GREEN = Seeed Studio ShenZhen OPL
1 | 32.768KHz | CRYSTALTC38H | TC38H | Y2_32.768KHZ | Crystal | - | SER3205-ND | 732-C002RX32.76K-EPB | - | C-002RX 32.7680K-E:PBFREE | CRYSTAL 32.768KHZ 6PF THRU
2 | 8pF | C-0603 | C0603 | C15, C16 | CAPACITOR, European symbol | 010023001 |  | - | 010023001 | CC0603DRNPO9BN8R2 | SMD CAP Ceramic 8.2pF-50V-0.5pF-NPO
YELLOW = Option for RTC Do Not Populate and do not include the items
Updated 26 Dec 2019 https://www.seeedstudio.com/opl.html

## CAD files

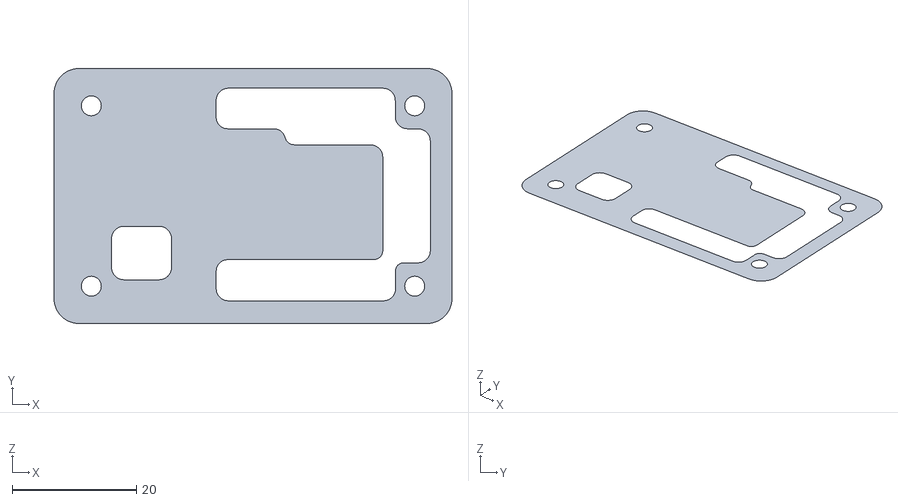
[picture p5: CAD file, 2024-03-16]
hardware/HydraBus_1_0_Rev1_SoBv1_DP6037/HydraBus_v1_0_Rev1_SoBv1_DP6037-Top_Bottom.stl
64.0 x 41.0 x 3.89e-14

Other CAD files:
hardware/HydraBus_1_0_Rev1_SoBv1_DP6037/HydraBus_v1_0_Rev1_SoBv1_DP6037-Top.skp
hardware/HydraBus_1_0_Rev1_SoBv1_DP6037/HydraBus_v1_0_Rev1_SoBv1_DP6037-Top_Bottom.dxf

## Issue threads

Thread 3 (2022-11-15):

STM32F405RGT6 unavailable

ClumsyPenguin, 2022-11-15:
The BOM states that the MCU is a STM32F405RGT6. However it seems to be nowhere in stock.
Is there an alternative with the same pinout? I am not that familiar with the STM32F4 series.

bvernoux, 2022-11-15:
Unfortunately there is no alternative(fully compatible) to that part and like lot of other MCU it is heavily impacted by chip shortage.

ClumsyPenguin, 2022-11-16:
FYI i got a notification that some of them are in stock on https://www.lcsc.com/product-detail/Microcontroller-Units-MCUs-MPUs-SOCs_STMicroelectronics-STM32F405RGT6_C15742.html

Closed 2025-04-02.

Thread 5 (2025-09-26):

PCB Dimensions

cnf, 2025-09-26:
Can we get the technical dimensions of the pcb please? The shield template doesn't import nicely, in kicad9, it would be nice to get the measurements of where to put the holes, and the headers, so we can create our own.

cnf, 2025-09-27:
I tried the import, but it didn't align things well.
I have figured out the placement of the holes, but the headers are another thing. I guess i'll try with calipers on my own hydrabus.

If i end up with something reusable, i'll share it.

bvernoux, 2025-09-27:
You can use HydraFlash as good template it is done with KiCad 4.x or more see https://github.com/hydrabus/HydraFlash

bvernoux, 2025-09-27:
I opened the KiCad project from https://github.com/AnttiNykanen/hydrabus-shield-template-kicad with KiCad 9.0.4 and it work fine without any issue

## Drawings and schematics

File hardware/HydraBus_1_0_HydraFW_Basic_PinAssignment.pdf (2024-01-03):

# Basic Pin Assignment

## USB Female Type C

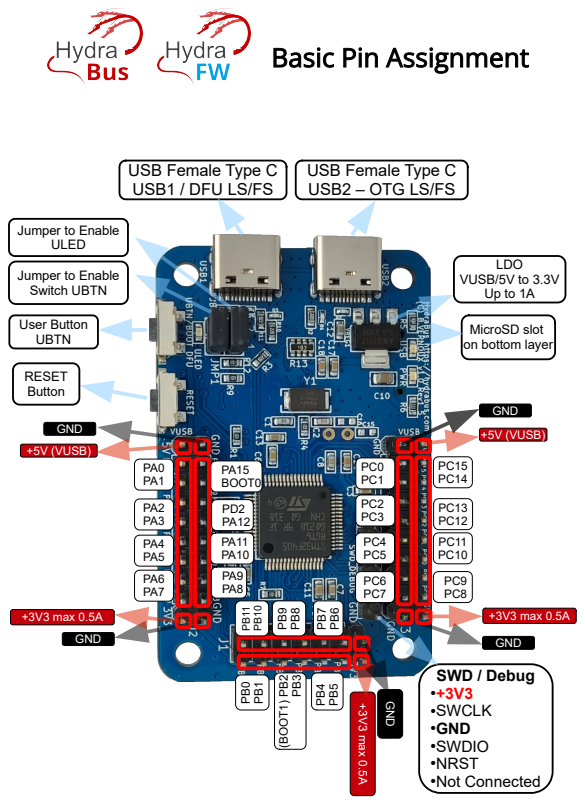
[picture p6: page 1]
+5V (VUSB); +3V3 max 0.5A; GND; LDO VUSB/5V to 3.3V Up to 1A; SWD / Debug ●+3V3 ●SWCLK ●GND ●SWDIO ●NRST ●Not Connected; PA15 BOOT0; RESET Button; User Button UBTN

USB Female Type C
USB1 / DFU LS/FS

USB2 – OTG LS/FS

Jumper to Enable
ULED

Switch UBTN

MicroSD slot
on bottom layer

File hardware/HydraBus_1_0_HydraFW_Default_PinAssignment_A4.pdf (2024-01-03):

# Pin Assignment

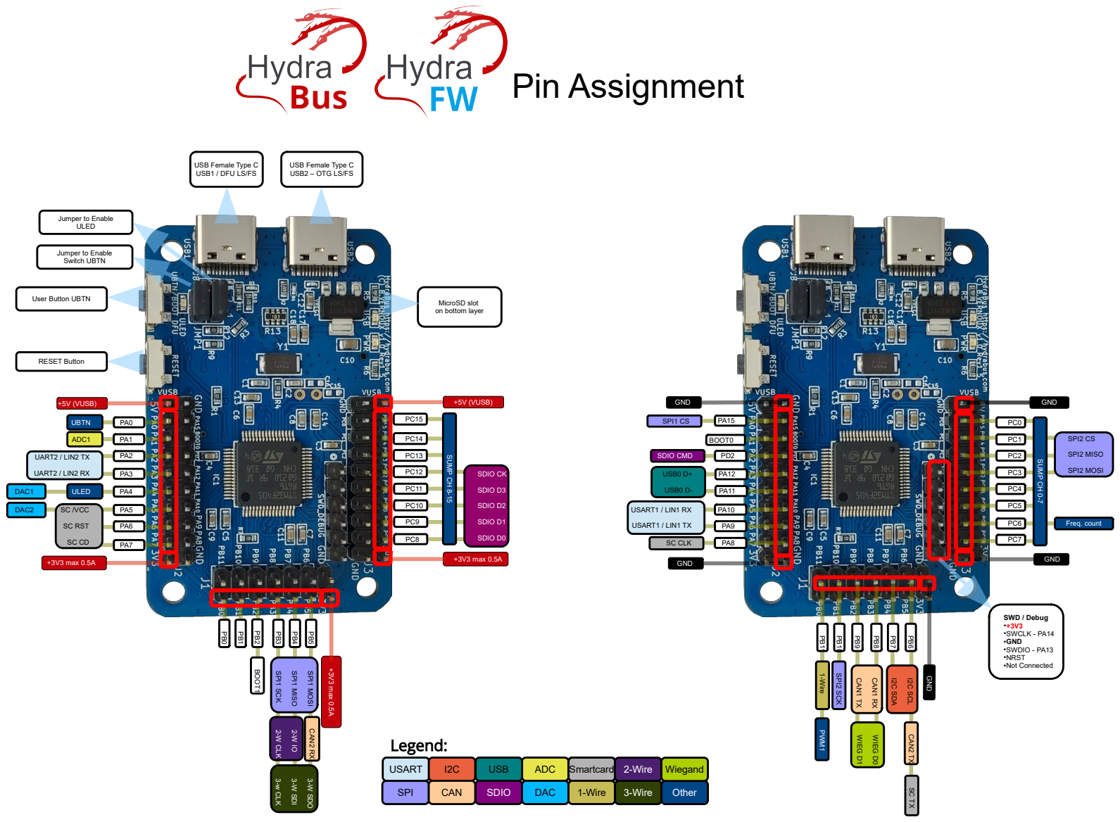
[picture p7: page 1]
+5V (VUSB); +3V3 max 0.5A; GND; SDIO CK; SDIO D3; SDIO D2; SDIO D1; SDIO D0; UBTN; ADC1; UART2 / LIN2 TX; UART2 / LIN2 RX; ULED; DAC2; DAC1; CAN2 RX; BOOT1; SPI1 MOSI; SPI1 MISO; SPI1 SCK; SC /VCC; SC RST; USART1 / LIN1 RX; USART1 / LIN1 TX; SC CLK; CAN1 RX; CAN1 TX; USB0 D+; USB0 D-; SDIO CMD; SPI1 CS; SPI2 CS; SPI2 MISO; SPI2 MOSI; 1-Wire; SPI2 SCK; I2C SCL; I2C SDA; 2-W CLK; 3-W SDO; 3-W SDI; 3-w CLK; Freq. count; PWM1; WIEG D0; WIEG D1; ADC; SPI; USART; SDIO; CAN; DAC; USB; Legend: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

USB Female Type C
USB1 / DFU LS/FS

USB2 – OTG LS/FS

Jumper to Enable
ULED

Switch UBTN

User Button UBTN

MicroSD slot
on bottom layer

CAN2 TX SC TX

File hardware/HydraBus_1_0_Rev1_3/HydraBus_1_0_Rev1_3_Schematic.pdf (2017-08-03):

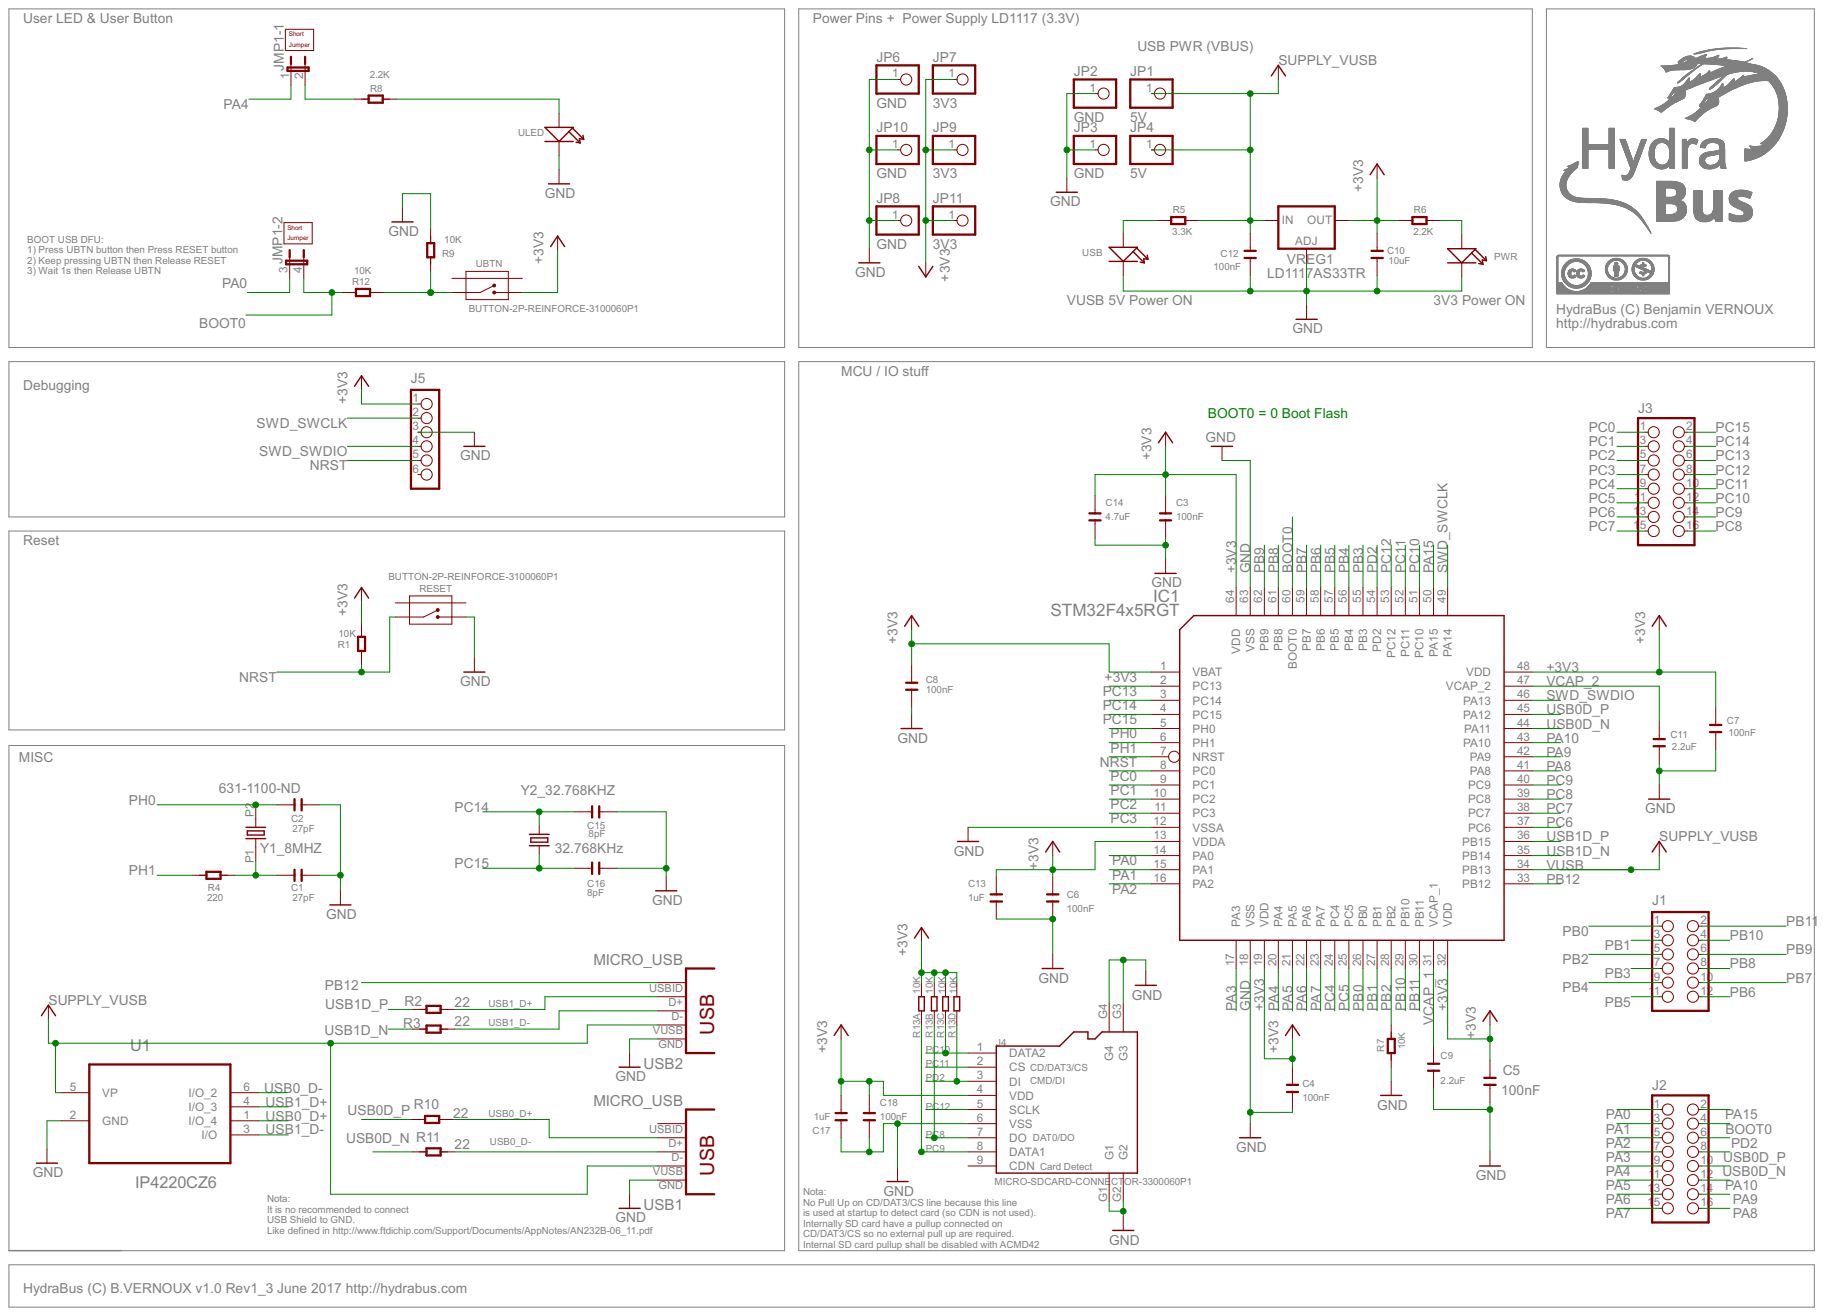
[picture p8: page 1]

User LED & User Button

Power Pins + Power Supply LD1117 (3.3V)
GND GND

BOOT USB DFU: 1) Press UBTN button then Press RESET button

2) Keep pressing UBTN then Release RESET
3) Wait 1s then Release UBTN

DATA2
CD/DAT3/CS CMD/DI Card Detect DAT0/DO

Nota:
It is no recommended to connect USB Shield to GND. Like defined in http://www.ftdichip.com/Support/Documents/AppNotes/AN232B-06_11.pdf

Nota: No Pull Up on CD/DAT3/CS line because this line

MICRO-SDCARD-CONNECTOR-3300060P1 GND

is used at startup to detect card (so CDN is not used).
Internally SD card have a pullup connected on CD/DAT3/CS so no external pull up are required.

Internal SD card pullup shall be disabled with ACMD42

HydraBus (C) B.VERNOUX v1.0 Rev1_3 June 2017 http://hydrabus.com

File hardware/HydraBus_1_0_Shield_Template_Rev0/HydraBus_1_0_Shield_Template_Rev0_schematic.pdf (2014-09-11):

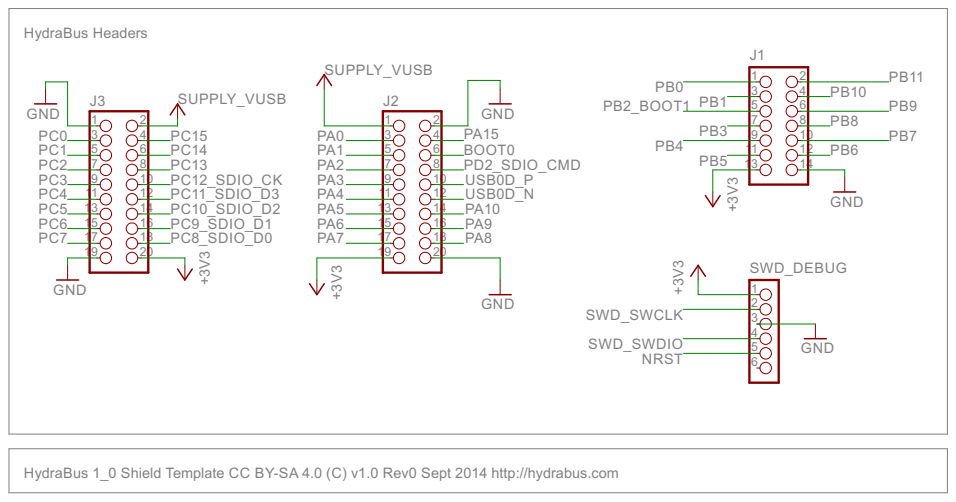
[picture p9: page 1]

HydraBus 1_0 Shield Template CC BY-SA 4.0 (C) v1.0 Rev0 Sept 2014 http://hydrabus.com

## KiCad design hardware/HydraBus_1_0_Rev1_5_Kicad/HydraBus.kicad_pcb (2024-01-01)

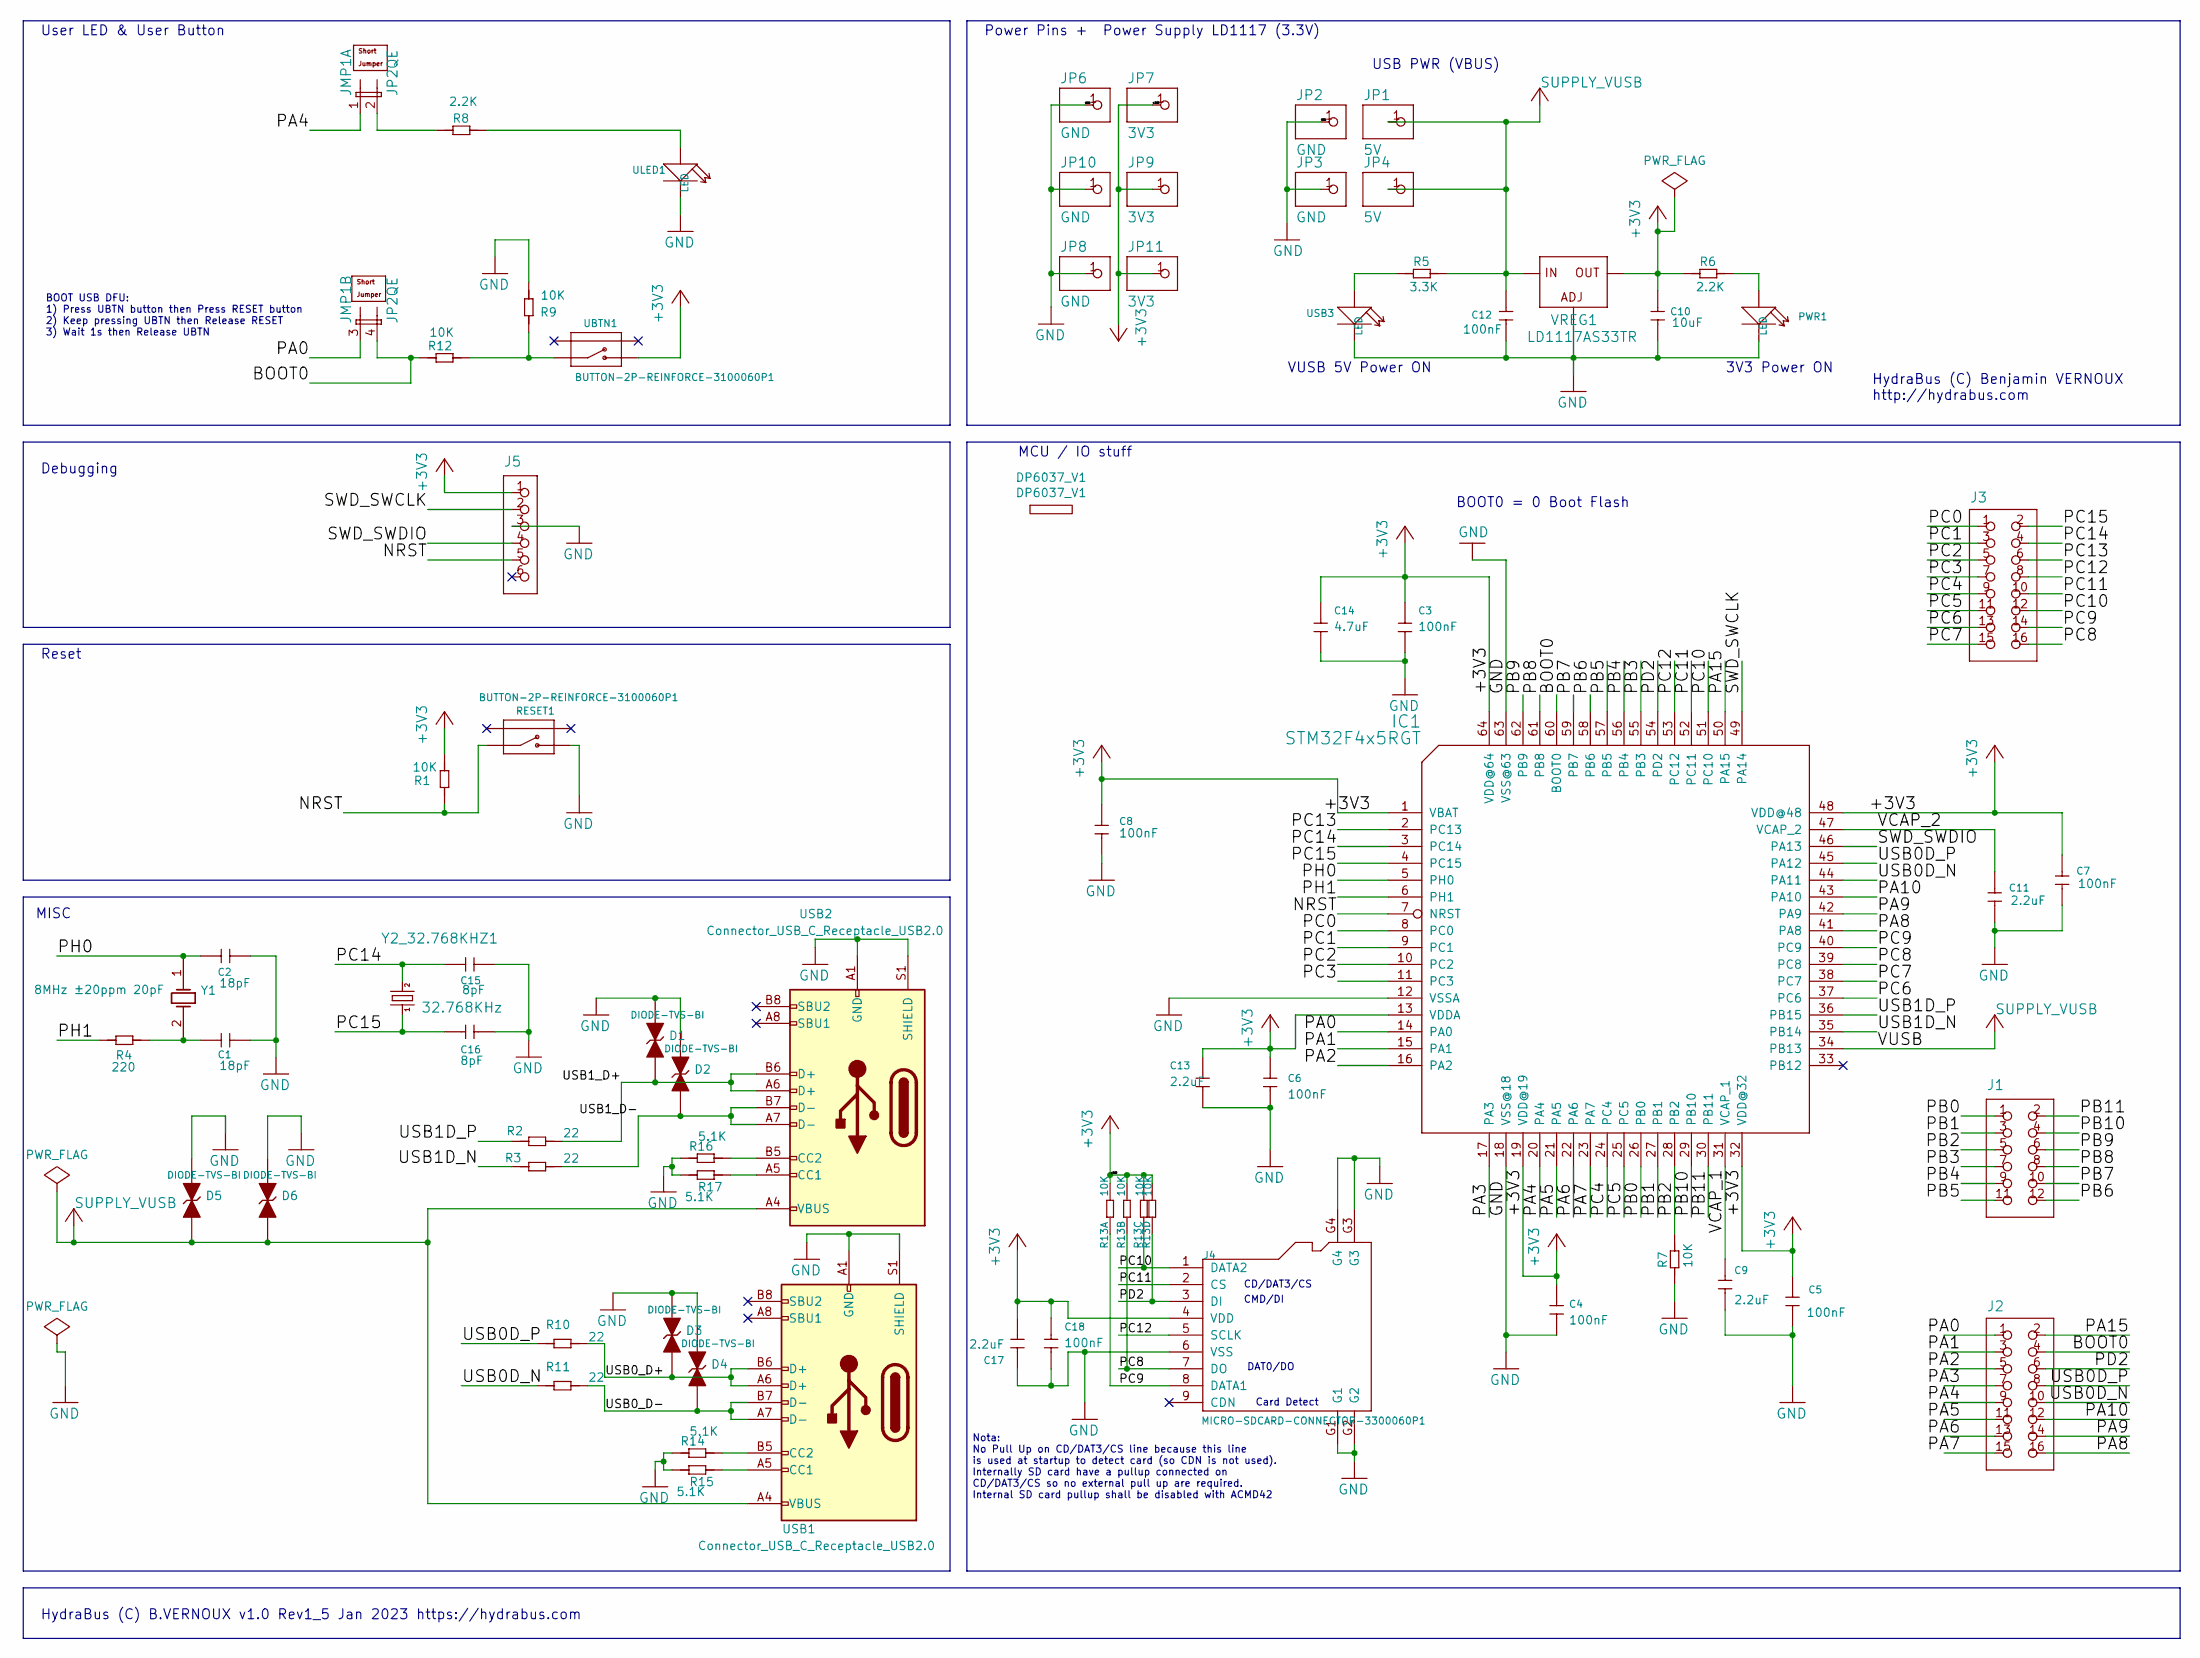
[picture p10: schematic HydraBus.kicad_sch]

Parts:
C1, C2: 18pF; C0603; LCSC_Part C1647
C3, C4, C5, C6, C7, C8, C12, C18: 100nF; C0603; LCSC_Part C14663
C9, C11, C13, C17: 2.2uF; C0603; LCSC_Part C23630
C10: 10uF; C0805; LCSC_Part C15850
C14: 4.7uF; C0603; LCSC_Part C19666
C15, C16: 8pF; C0603
D1, D2, D3, D4, D5, D6: DIODE-TVS-BI; 0402; LCSC_Part C191267
DP6037_V1: DP6037_V1
IC1: STM32F4x5RGT; LQFP64; LCSC_Part C15742
J1: CON_HEADER_2X07; M2X6; LCSC_Part PRPC007DFBN-RC
J2, J3: CON_HEADER_2X10; M2X8; LCSC_Part PRPC010DFBN-RC
J4: MICRO-SDCARD-CONNECTOR-3300060P1; 9P-SMD-W-RING; LCSC_Part C341092
J5: CON_HEADER_1X06-PTH; M1X6; LCSC_Part PEC06SFBN
JMP1: JP2QE; JP2Q
JMP_UBTN1: SHORT-JUMPER-2P-3460440P1; 2P-2.54
JMP_ULED1: SHORT-JUMPER-2P-3460440P1; 2P-2.54
JP1, JP4: 5V; 1X01
JP2, JP3, JP6, JP8, JP10: GND; 1X01
JP7, JP9, JP11: 3V3; 1X01
PWR1: LED; LED0603; LCSC_Part C72043
R1, R7, R9, R12: 10K; R0603; LCSC_Part C25804
R2, R3, R10, R11: 22; R0603; LCSC_Part C23345
R4: 220; R0603; LCSC_Part C22962
R5: 3.3K; R0603; LCSC_Part C22978
R6, R8: 2.2K; R0603; LCSC_Part C4190
R13: 10K; R1206-8; LCSC_Part C29718
R14, R15, R16, R17: 5.1K; R0603; LCSC_Part C23186
RESET1: BUTTON-2P-REINFORCE-3100060P1; 4P-SMD-7.0X3.5X3.5H-90D
UBTN1: BUTTON-2P-REINFORCE-3100060P1; 4P-SMD-7.0X3.5X3.5H-90D
ULED1: LED; LED0603; LCSC_Part C72043
USB1, USB2: Connector_USB_C_Receptacle_USB2.0; TYPE-C-31-M-12; LCSC_Part C165948
USB3: LED; LED0603; LCSC_Part C72043
VREG1: LD1117AS33TR; SOT223; LCSC_Part C115288
Y1: SMD-5032_2P_8MHz_20ppm_20pF; SMD-5032_2P; LCSC_Part C115962
Y2_32.768KHZ1: 32.768KHz; TC38H

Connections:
/BOOT0: IC1.60 (BOOT0), J2.4, JMP1.4 (2), R12.2
/NRST: IC1.7 (NRST), J5.5, R1.1, RESET1.1
/PA0: IC1.14 (PA0), J2.1, JMP1.3 (1)
/PA1: IC1.15 (PA1), J2.3
/PA2: IC1.16 (PA2), J2.5
/PA3: IC1.17 (PA3), J2.7
/PA4: IC1.20 (PA4), J2.9, JMP1.1
/PA5: IC1.21 (PA5), J2.11
/PA6: IC1.22 (PA6), J2.13
/PA7: IC1.23 (PA7), J2.15
/PA8: IC1.41 (PA8), J2.16
/PA9: IC1.42 (PA9), J2.14
/PA10: IC1.43 (PA10), J2.12
/PA15: IC1.50 (PA15), J2.2
/PB0: IC1.26 (PB0), J1.1
/PB1: IC1.27 (PB1), J1.3
/PB2: IC1.28 (PB2), J1.5, R7.1
/PB3: IC1.55 (PB3), J1.7
/PB4: IC1.56 (PB4), J1.9
/PB5: IC1.57 (PB5), J1.11
/PB6: IC1.58 (PB6), J1.12
/PB7: IC1.59 (PB7), J1.10
/PB8: IC1.61 (PB8), J1.8
/PB9: IC1.62 (PB9), J1.6
/PB10: IC1.29 (PB10), J1.4
/PB11: IC1.30 (PB11), J1.2
/PC0: IC1.8 (PC0), J3.1
/PC1: IC1.9 (PC1), J3.3
/PC2: IC1.10 (PC2), J3.5
/PC3: IC1.11 (PC3), J3.7
/PC4: IC1.24 (PC4), J3.9
/PC5: IC1.25 (PC5), J3.11
/PC6: IC1.37 (PC6), J3.13
/PC7: IC1.38 (PC7), J3.15
/PC8: IC1.39 (PC8), J3.16, J4.7 (DO), R13.2 (1)
/PC9: IC1.40 (PC9), J3.14, J4.8 (DATA1), R13.1
/PC10: IC1.51 (PC10), J3.12, J4.1 (DATA2), R13.3 (1)
/PC11: IC1.52 (PC11), J3.10, J4.2 (CS)
/PC12: IC1.53 (PC12), J3.8, J4.5 (SCLK)
/PC13: IC1.2 (PC13), J3.6
/PC14: C15.1, IC1.3 (PC14), J3.4, Y2_32.768KHZ1.2
/PC15: C16.1, IC1.4 (PC15), J3.2, Y2_32.768KHZ1.1
/PD2: IC1.54 (PD2), J2.6, J4.3 (DI), R13.4 (1)
/PH0: C2.1, IC1.5 (PH0), Y1.1 (OSC1)
/PH1: IC1.6 (PH1), R4.2
/SWD_SWCLK: IC1.49 (PA14), J5.2
/SWD_SWDIO: IC1.46 (PA13), J5.4
/USB0D_N: IC1.44 (PA11), J2.10, R11.2
/USB0D_P: IC1.45 (PA12), J2.8, R10.2
/USB0_D+: D3.1 (A), R10.1, USB1.A6 (D+), USB1.B6 (D+)
/USB0_D-: D4.1 (A), R11.1, USB1.A7 (D-), USB1.B7 (D-)
/USB1D_N: IC1.35 (PB14), R3.2
/USB1D_P: IC1.36 (PB15), R2.2
/USB1_D+: D1.1 (A), R2.1, USB2.A6 (D+), USB2.B6 (D+)
/USB1_D-: D2.1 (A), R3.1, USB2.A7 (D-), USB2.B7 (D-)
/VCAP_1: C9.2, IC1.31 (VCAP_1)
/VCAP_2: C11.1, IC1.47 (VCAP_2)
unnamed: C1.1, R4.1, Y1.2 (OSC2)
unnamed: JMP1.2, R8.2
unnamed: PWR1.+, R6.1
unnamed: R5.2, USB3.+
unnamed: R8.1, ULED1.+
unnamed: R9.1, R12.1, UBTN1.1
unnamed: R14.1, USB1.B5 (CC2)
unnamed: R15.2, USB1.A5 (CC1)
unnamed: R16.1, USB2.B5 (CC2)
unnamed: R17.2, USB2.A5 (CC1)
VBUS: C12.1, D5.1 (A), D6.1 (A), IC1.34 (PB13), JP1.1, JP4.1, R5.1, USB1.A4 (VBUS), USB1.A9 (VBUS), USB1.B4 (VBUS), USB1.B9 (VBUS), USB2.A4 (VBUS), USB2.A9 (VBUS), USB2.B4 (VBUS), USB2.B9 (VBUS), VREG1.3 (IN)

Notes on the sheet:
Debugging
BOOT USB DFU: 1) Press UBTN button then Press RESET button 2) Keep pressing UBTN then Release RESET 3) Wait 1s then Release UBTN
Card Detect
HydraBus (C) Benjamin VERNOUX http://hydrabus.com
MCU / IO stuff
BOOT0 = 0 Boot Flash
3V3 Power ON
USB PWR (VBUS)
CMD/DI
VUSB 5V Power ON
CD/DAT3/CS
User LED & User Button
Reset
HydraBus (C) B.VERNOUX v1.0 Rev1_5 Jan 2023 https://hydrabus.com
Power Pins + Power Supply LD1117 (3.3V)
DAT0/DO
Nota: No Pull Up on CD/DAT3/CS line because this line is used at startup to detect card (so CDN is not used). Internally SD card have a pullup connected on CD/DAT3/CS so no external pull up are required. Internal SD card pullup shall be disabled with ACMD42
MISC

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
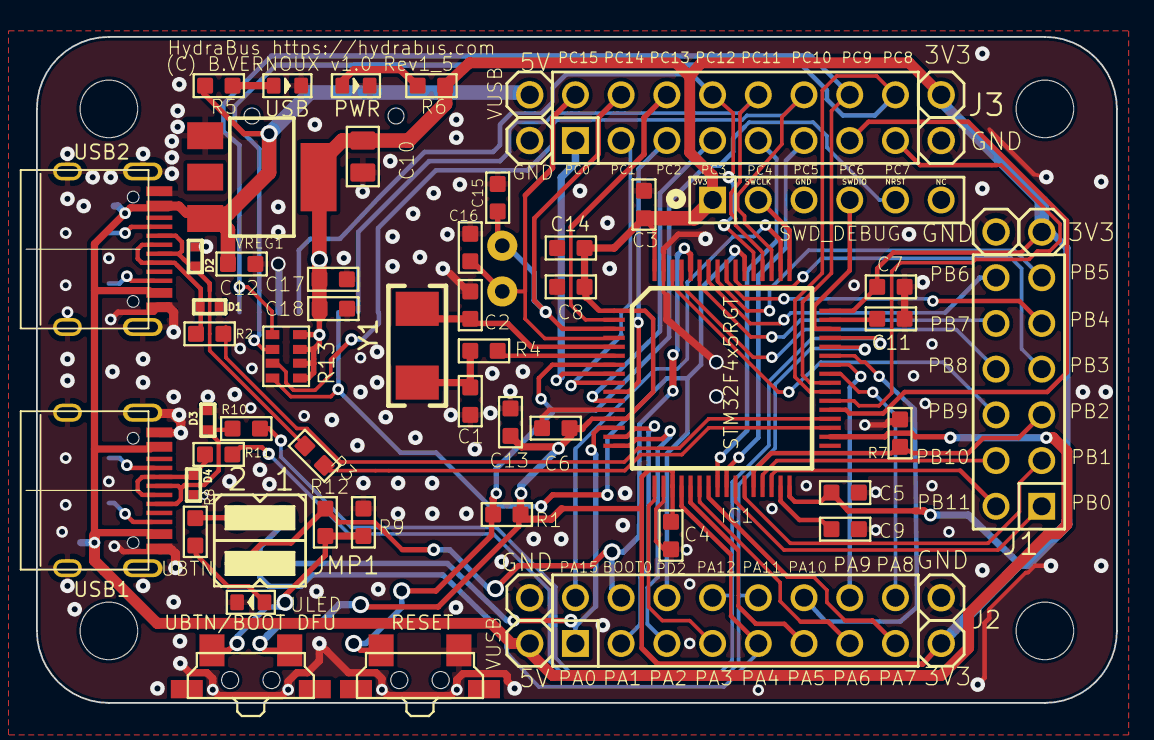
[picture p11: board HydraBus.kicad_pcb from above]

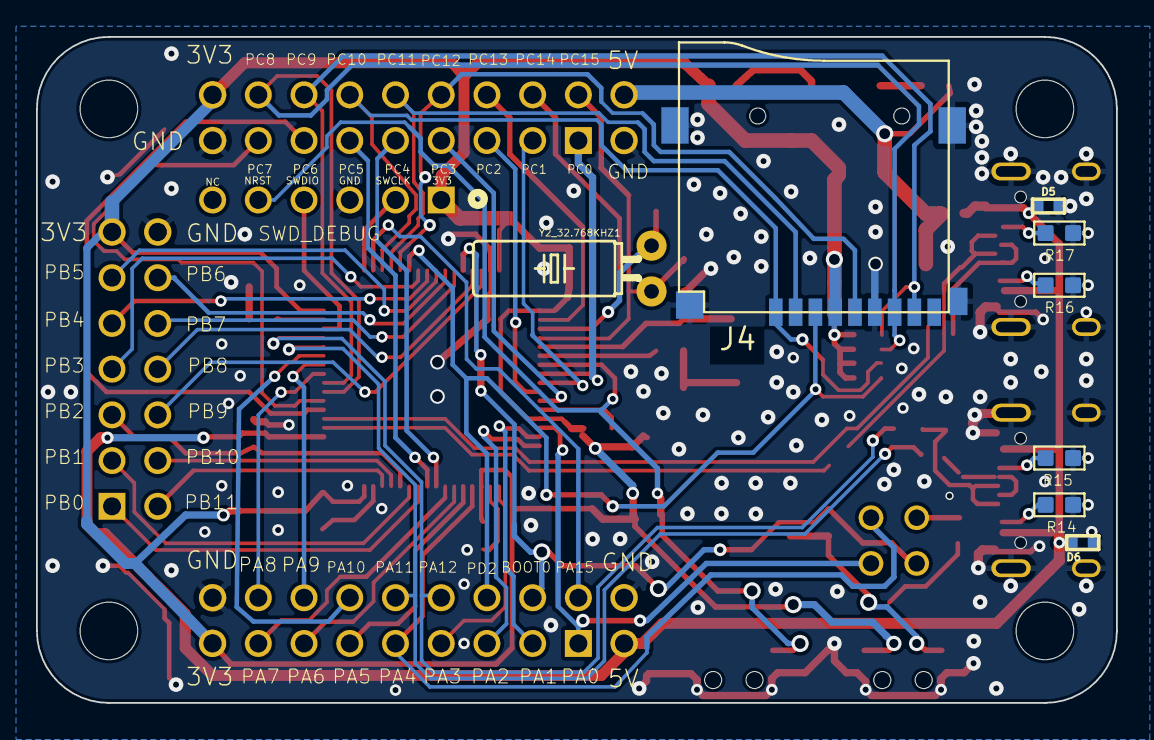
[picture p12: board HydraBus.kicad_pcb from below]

Board: 2 copper layers, 60.0 x 37.0 mm, 71 parts (8 on the bottom side), 70 nets.

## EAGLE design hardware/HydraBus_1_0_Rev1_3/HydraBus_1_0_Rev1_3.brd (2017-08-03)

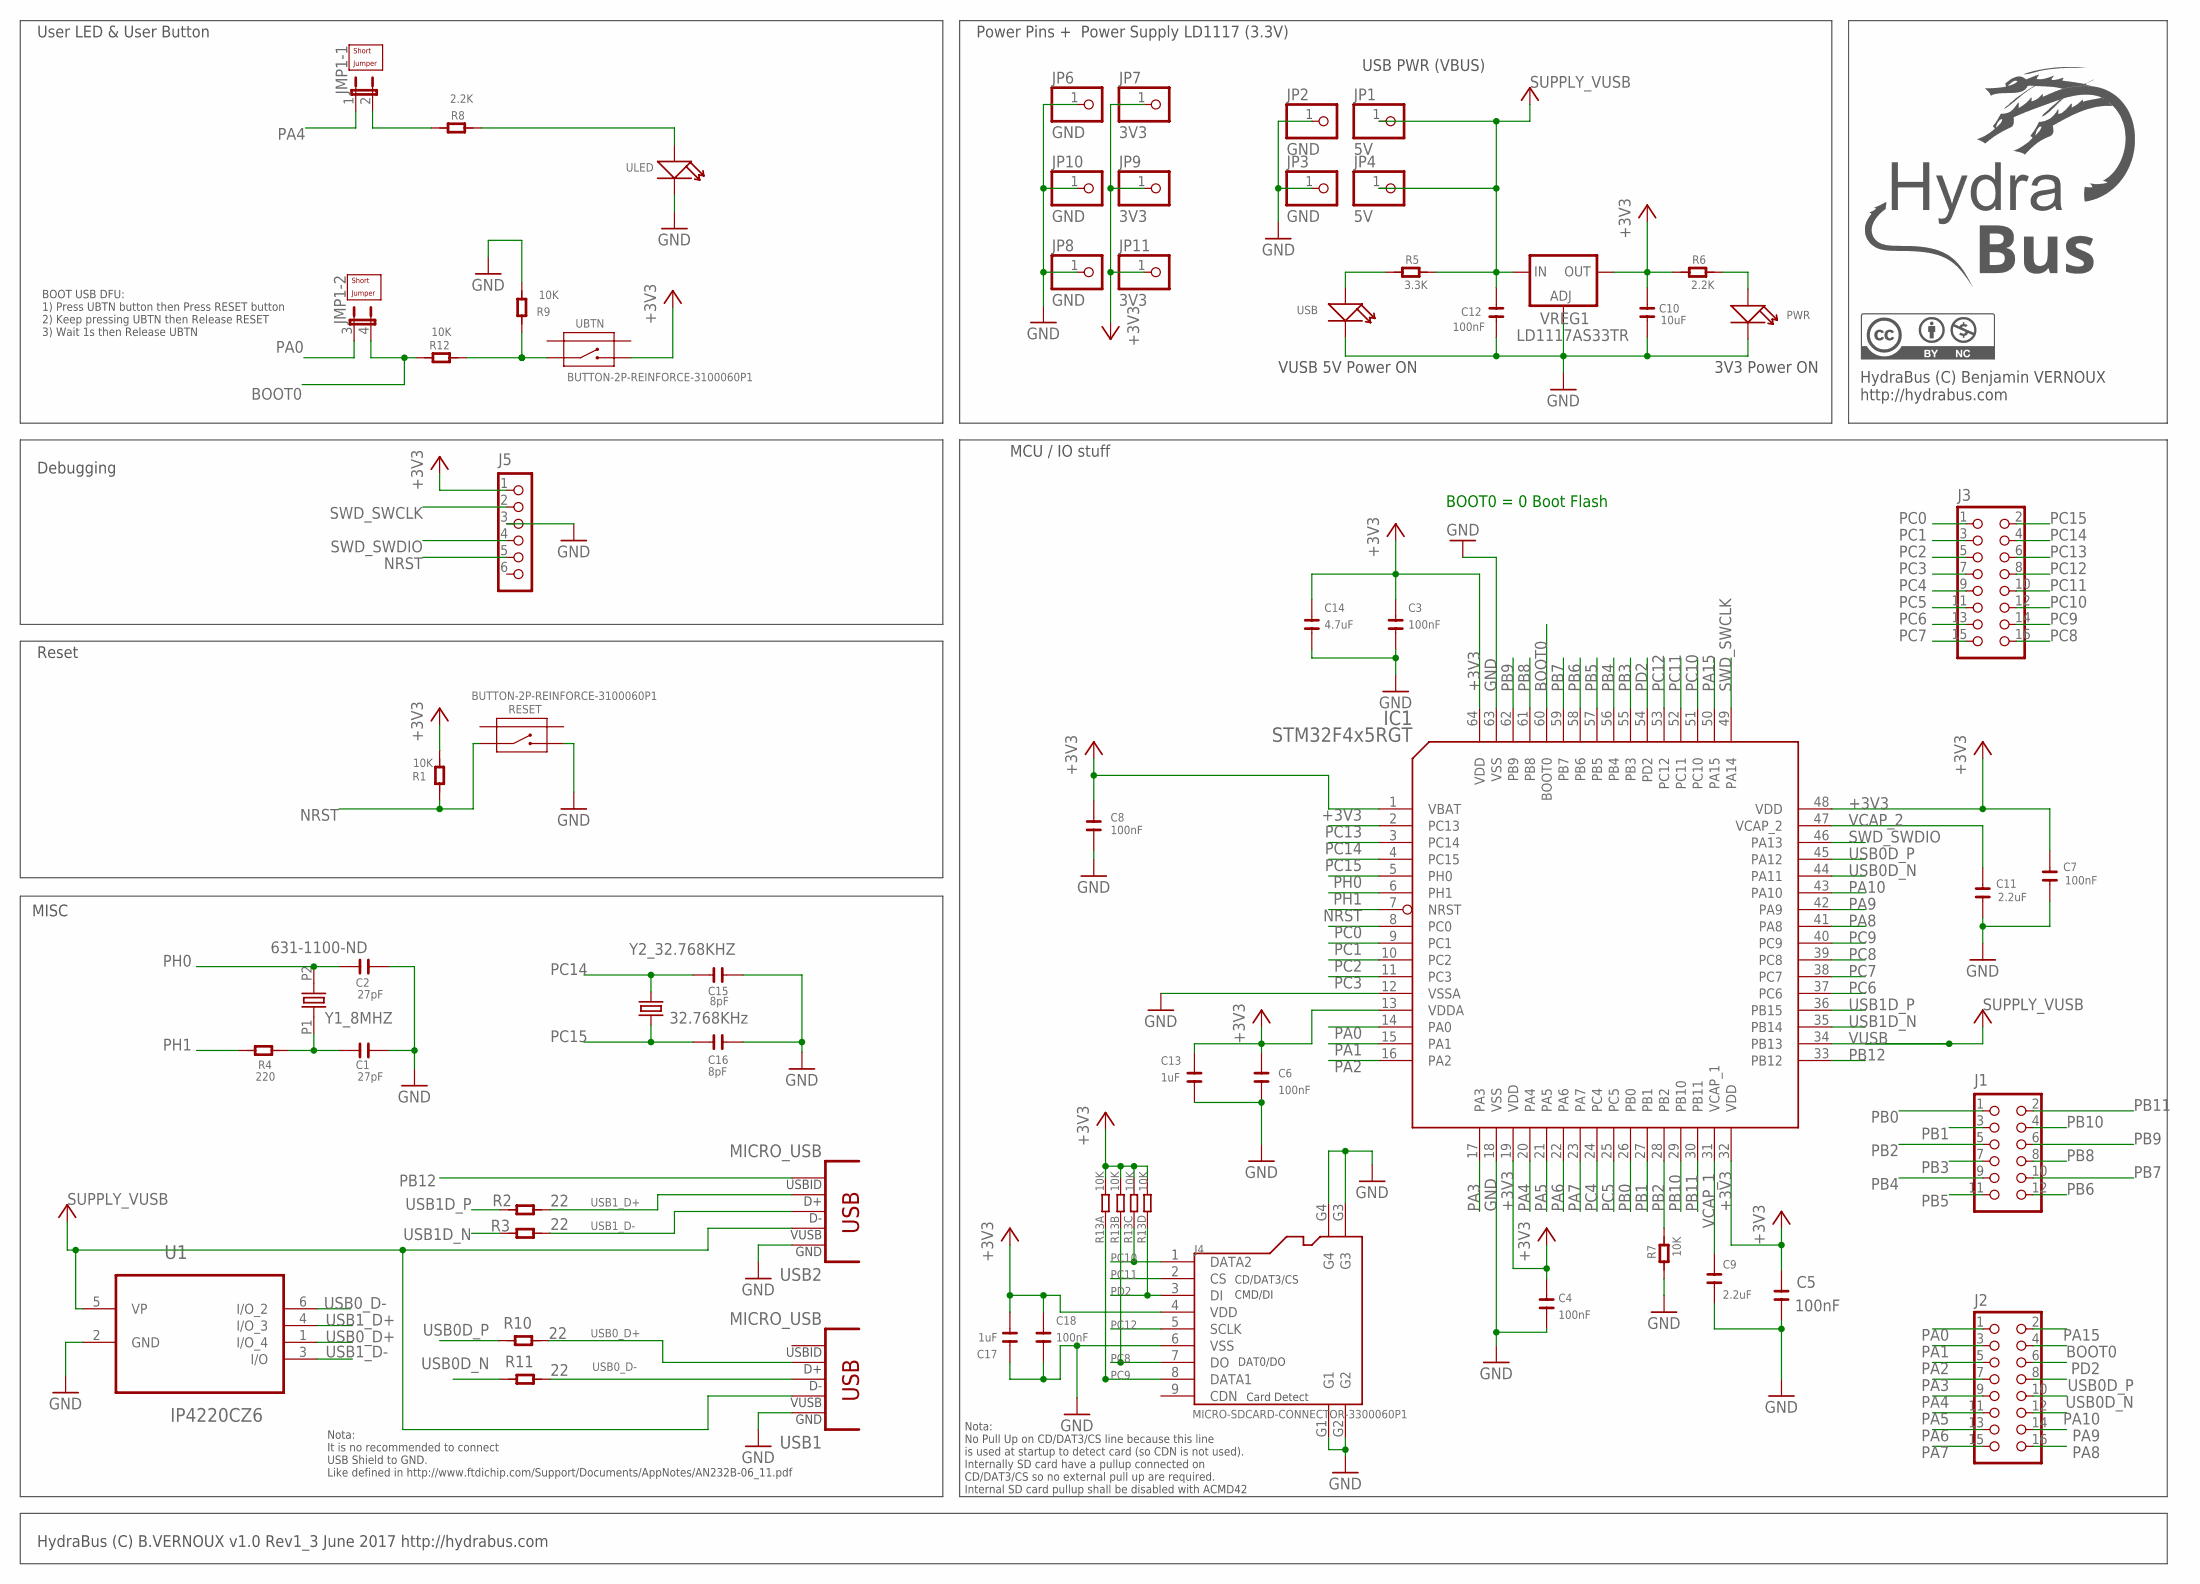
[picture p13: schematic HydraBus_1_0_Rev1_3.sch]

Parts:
C1, C2: 27pF; C0603
C3, C4, C5, C6, C7, C8, C12, C18: 100nF; C0603
C9, C11: 2.2uF; C0603
C10: 10uF; C0805
C13, C17: 1uF; C0603
C14: 4.7uF; C0603
C15, C16: 8pF; C0603
IC1: STM32F4x5RGT; LQFP64
J1: CON_HEADER_2X06; M2X6
J2, J3: CON_HEADER_2X08; M2X8
J4: MICRO-SDCARD-CONNECTOR-3300060P1; 9P-SMD-W-RING
J5: CON_HEADER_1X06-PTH; M1X6
JMP1: JP2QE; JP2Q
JMP_UBTN: SHORT-JUMPER-2P-3460440P1; 2P-2.54
JMP_ULED: SHORT-JUMPER-2P-3460440P1; 2P-2.54
JP1, JP4: 5V; 1X01
JP2, JP3, JP6, JP8, JP10: GND; 1X01
JP7, JP9, JP11: 3V3; 1X01
PWR: LED; LED0603
R1, R7, R9, R12: 10K; R0603
R2, R3, R10, R11: 22; R0603
R4: 220; R0603
R5: 3.3K; R0603
R6, R8: 2.2K; R0603
R13: 10K; R1206-8
RESET: BUTTON-2P-REINFORCE-3100060P1; 4P-SMD-7.0X3.5X3.5H-90D
U1: IP4220CZ6; SOT95P275X110-6N
UBTN: BUTTON-2P-REINFORCE-3100060P1; 4P-SMD-7.0X3.5X3.5H-90D
ULED: LED; LED0603
USB: LED; LED0603
USB1, USB2: MICRO_USB; MICRO_USB5+6P_SMD_0_65
VREG1: LD1117AS33TR; SOT223
Y1_8MHZ: 631-1100-ND; HC-49U-PTH
Y2_32.768KHZ: 32.768KHz; TC38H

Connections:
+3V3: C3.1, C4.1, C5.2, C6.1, C7.1, C8.1, C10.1, C13.1, C14.1, C17.2, C18.1, IC1.1 (VBAT), IC1.13 (VDDA), IC1.19 (VDD), IC1.32 (VDD), IC1.48 (VDD), IC1.64 (VDD), J4.4 (VDD), J5.1, JP7.1, JP9.1, JP11.1, R1.2, R6.2, R13.5 (2), R13.6 (2), R13.7 (2), R13.8 (2), UBTN.2, VREG1.4 (OUT)
BOOT0: IC1.60 (BOOT0), J2.4, JMP1.4 (2), R12.2
GND: C1.2, C2.2, C3.2, C4.2, C5.1, C6.2, C7.2, C8.2, C9.1, C10.2, C11.2, C12.2, C13.2, C14.2, C15.2, C16.2, C17.1, C18.2, IC1.12 (VSSA), IC1.18 (VSS), IC1.63 (VSS), J4.6 (VSS), J4.G1, J4.G2, J4.G3, J4.G4, J5.3, JP2.1, JP3.1, JP6.1, JP8.1, JP10.1, PWR.-, R7.2, R9.2, RESET.2, U1.2 (GND), ULED.-, USB.-, USB1.5 (GND), USB2.5 (GND), VREG1.1 (ADJ)
unnamed: C1.1, R4.1, Y1_8MHZ.P1 (1)
unnamed: JMP1.2, R8.2
unnamed: R9.1, R12.1, UBTN.1
unnamed: R8.1, ULED.+
unnamed: R5.2, USB.+
unnamed: PWR.+, R6.1
NRST: IC1.7 (NRST), J5.5, R1.1, RESET.1
PA0: IC1.14 (PA0), J2.1, JMP1.3 (1)
PA1: IC1.15 (PA1), J2.3
PA2: IC1.16 (PA2), J2.5
PA3: IC1.17 (PA3), J2.7
PA4: IC1.20 (PA4), J2.9, JMP1.1
PA5: IC1.21 (PA5), J2.11
PA6: IC1.22 (PA6), J2.13
PA7: IC1.23 (PA7), J2.15
PA8: IC1.41 (PA8), J2.16
PA9: IC1.42 (PA9), J2.14
PA10: IC1.43 (PA10), J2.12
PA15: IC1.50 (PA15), J2.2
PB0: IC1.26 (PB0), J1.1
PB1: IC1.27 (PB1), J1.3
PB2: IC1.28 (PB2), J1.5, R7.1
PB3: IC1.55 (PB3), J1.7
PB4: IC1.56 (PB4), J1.9
PB5: IC1.57 (PB5), J1.11
PB6: IC1.58 (PB6), J1.12
PB7: IC1.59 (PB7), J1.10
PB8: IC1.61 (PB8), J1.8
PB9: IC1.62 (PB9), J1.6
PB10: IC1.29 (PB10), J1.4
PB11: IC1.30 (PB11), J1.2
PB12: IC1.33 (PB12), USB2.4 (USBID)
PC0: IC1.8 (PC0), J3.1
PC1: IC1.9 (PC1), J3.3
PC2: IC1.10 (PC2), J3.5
PC3: IC1.11 (PC3), J3.7
PC4: IC1.24 (PC4), J3.9
PC5: IC1.25 (PC5), J3.11
PC6: IC1.37 (PC6), J3.13
PC7: IC1.38 (PC7), J3.15
PC8: IC1.39 (PC8), J3.16, J4.7 (DO), R13.2 (1)
PC9: IC1.40 (PC9), J3.14, J4.8 (DATA1), R13.1
PC10: IC1.51 (PC10), J3.12, J4.1 (DATA2), R13.3 (1)
PC11: IC1.52 (PC11), J3.10, J4.2 (CS)
PC12: IC1.53 (PC12), J3.8, J4.5 (SCLK)
PC13: IC1.2 (PC13), J3.6
PC14: C15.1, IC1.3 (PC14), J3.4, Y2_32.768KHZ.2
PC15: C16.1, IC1.4 (PC15), J3.2, Y2_32.768KHZ.1
PD2: IC1.54 (PD2), J2.6, J4.3 (DI), R13.4 (1)
PH0: C2.1, IC1.5 (PH0), Y1_8MHZ.P2 (2)
PH1: IC1.6 (PH1), R4.2
SWD_SWCLK: IC1.49 (PA14), J5.2
SWD_SWDIO: IC1.46 (PA13), J5.4
USB0D_N: IC1.44 (PA11), J2.10, R11.2
USB0D_P: IC1.45 (PA12), J2.8, R10.2
USB0_D+: R10.1, U1.1 (I/O_4), USB1.3 (D+)
USB0_D-: R11.1, U1.6 (I/O_2), USB1.2 (D-)
USB1D_N: IC1.35 (PB14), R3.2
USB1D_P: IC1.36 (PB15), R2.2
USB1_D+: R2.1, U1.4 (I/O_3), USB2.3 (D+)
USB1_D-: R3.1, U1.3 (I/O), USB2.2 (D-)
VCAP_1: C9.2, IC1.31 (VCAP_1)
VCAP_2: C11.1, IC1.47 (VCAP_2)
VUSB: C12.1, IC1.34 (PB13), JP1.1, JP4.1, R5.1, U1.5 (VP), USB1.1 (VUSB), USB2.1 (VUSB), VREG1.3 (IN)

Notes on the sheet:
Debugging
Power Pins + Power Supply LD1117 (3.3V)
MCU / IO stuff
MISC
Reset
BOOT0 = 0 Boot Flash
USB PWR (VBUS)
3V3 Power ON
VUSB 5V Power ON
HydraBus (C) B.VERNOUX v1.0 Rev1_3 June 2017 http://hydrabus.com
User LED & User Button
CD/DAT3/CS
CMD/DI
Card Detect
DAT0/DO
Nota: No Pull Up on CD/DAT3/CS line because this line is used at startup to detect card (so CDN is not used). Internally SD card have a pullup connected on CD/DAT3/CS so no external pull up are required. Internal SD card pullup shall be disabled with ACMD42
HydraBus (C) Benjamin VERNOUX http://hydrabus.com
Nota: It is no recommended to connect USB Shield to GND. Like defined in http://www.ftdichip.com/Support/Documents/AppNotes/AN232B-06_11.pdf
BOOT USB DFU: 1) Press UBTN button then Press RESET button 2) Keep pressing UBTN then Release RESET 3) Wait 1s then Release UBTN

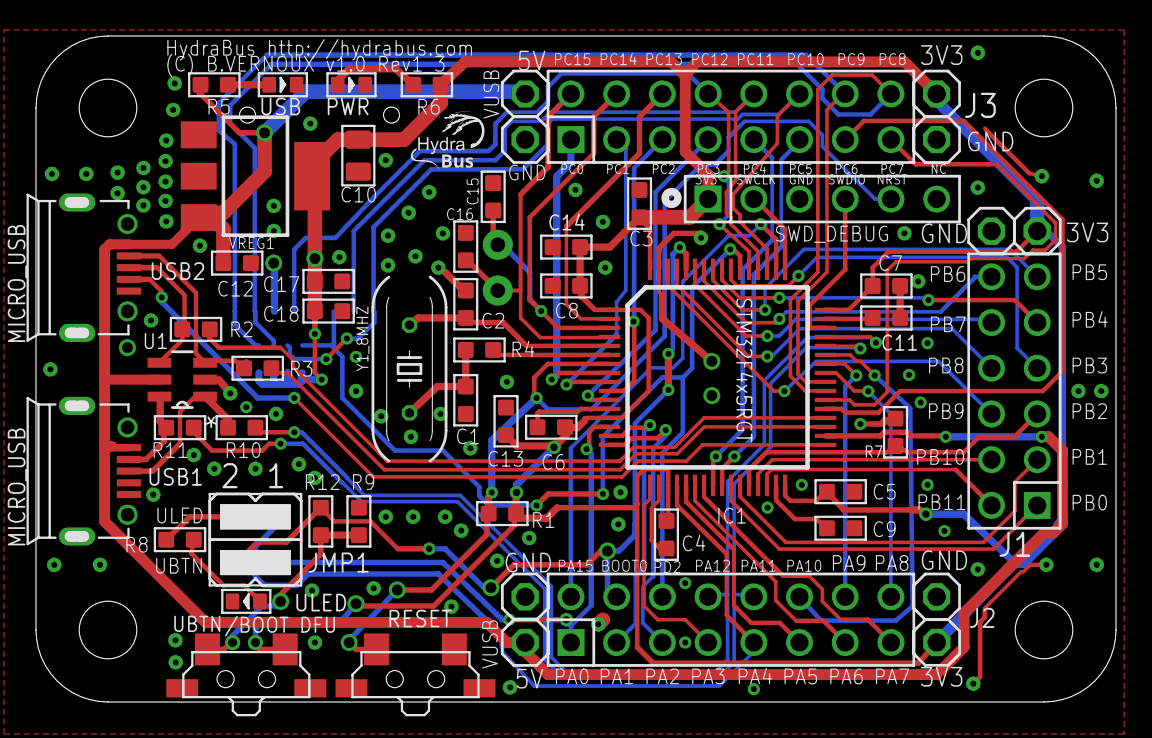
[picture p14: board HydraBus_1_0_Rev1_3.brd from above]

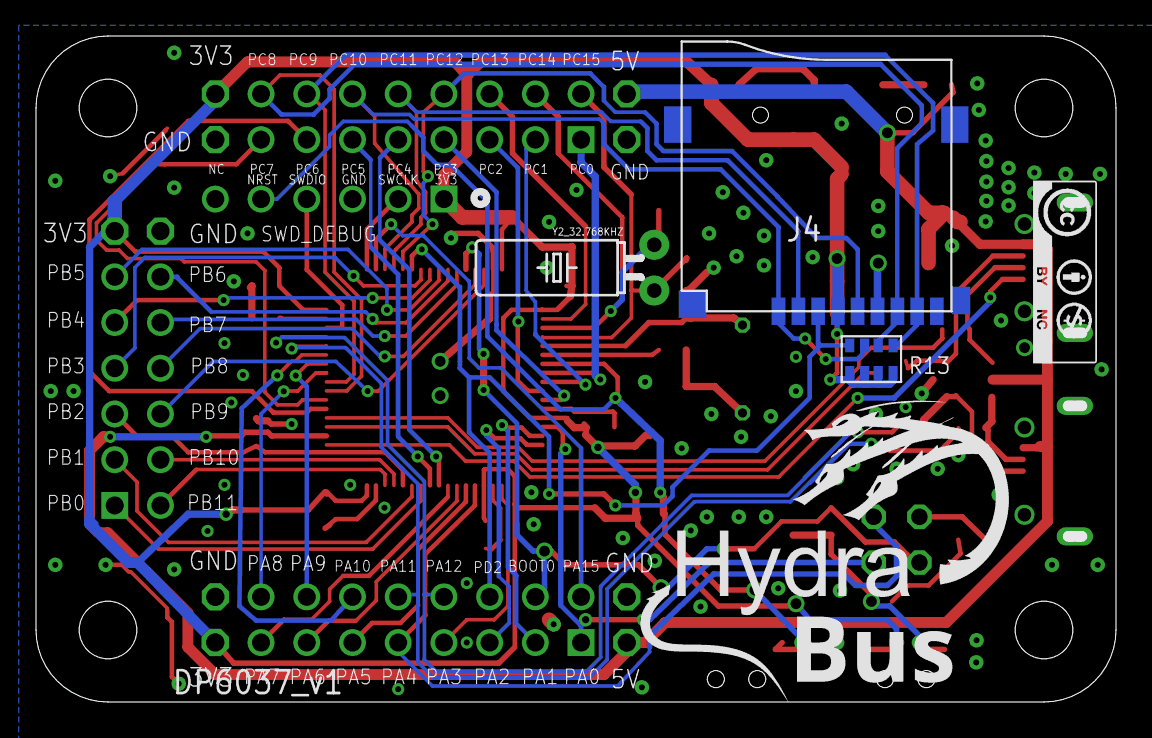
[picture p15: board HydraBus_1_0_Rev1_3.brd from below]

Board: 2 copper layers, 60.0 x 37.0 mm, 62 parts (3 on the bottom side), 67 nets.

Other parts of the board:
U$1: DP6037_V1

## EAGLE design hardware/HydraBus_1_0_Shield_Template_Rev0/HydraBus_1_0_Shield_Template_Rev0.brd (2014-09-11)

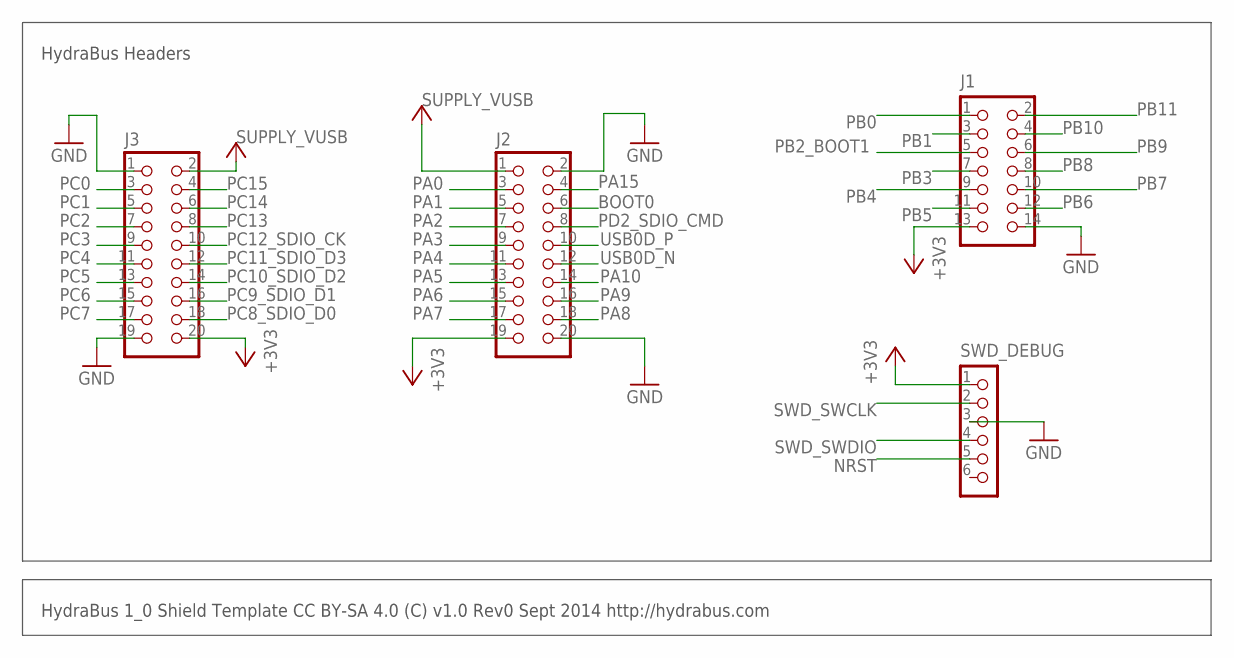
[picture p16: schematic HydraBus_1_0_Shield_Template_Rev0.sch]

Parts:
J1: HYDRABUS_SHIELD_CON_HEADER_2X07; HYDRABUS_SHIELD_M2X7
J2, J3: HYDRABUS_SHIELD_CON_HEADER_2X10; HYDRABUS_SHIELD_M2X10
SWD_DEBUG: HYDRABUS_SHIELD_CON_HEADER_1X06; HYDRABUS_SHIELD_M1X6

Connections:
+3V3: J1.13, J2.19, J3.20, SWD_DEBUG.1
BOOT0: J2.6
GND: J1.14, J2.2, J2.20, J3.1, J3.19, SWD_DEBUG.3
NRST: SWD_DEBUG.5
PA0: J2.3
PA1: J2.5
PA2: J2.7
PA3: J2.9
PA4: J2.11
PA5: J2.13
PA6: J2.15
PA7: J2.17
PA8: J2.18
PA9: J2.16
PA10: J2.14
PA15: J2.4
PB0: J1.1
PB1: J1.3
PB2_BOOT1: J1.5
PB3: J1.7
PB4: J1.9
PB5: J1.11
PB6: J1.12
PB7: J1.10
PB8: J1.8
PB9: J1.6
PB10: J1.4
PB11: J1.2
PC0: J3.3
PC1: J3.5
PC2: J3.7
PC3: J3.9
PC4: J3.11
PC5: J3.13
PC6: J3.15
PC7: J3.17
PC8_SDIO_D0: J3.18
PC9_SDIO_D1: J3.16
PC10_SDIO_D2: J3.14
PC11_SDIO_D3: J3.12
PC12_SDIO_CK: J3.10
PC13: J3.8
PC14: J3.6
PC15: J3.4
PD2_SDIO_CMD: J2.8
SWD_SWCLK: SWD_DEBUG.2
SWD_SWDIO: SWD_DEBUG.4
USB0D_N: J2.12
USB0D_P: J2.10
VUSB: J2.1, J3.2

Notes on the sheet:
HydraBus 1_0 Shield Template CC BY-SA 4.0 (C) v1.0 Rev0 Sept 2014 http://hydrabus.com
HydraBus Headers

Board: 2 copper layers, 4 parts (0 on the bottom side), 3 nets, no tracks yet.

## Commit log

2014-06-02 HydraBus board
2014-09-11 HydraBus hardware files Eagle, PDF, xls ...
    [HydraBus_1_0_Rev1_1.brd, HydraBus_1_0_Rev1_1.sch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]
2014-09-11 Added board
2014-09-30 HydraBus1.0 Sick Of Beige Case
    [HydraBus_v1_0_Rev1_SoBv1_DP6037-Top.skp]
2014-09-30 Windows XP, Vista, 7 and 8 drivers for HydraBus firmware USB CDC Virtual Serial Port.
2014-09-30 HydraBus1.0 Pin & Pin Assignment updated.
    [HydraBus_1_0_pins.ods]
2014-10-13 Removed STM32F4_USB_DFU_Driver.zip
2014-12-01 Added HydraBus Basic Pin Assignment
2015-01-01 Updated Default Pin Assignment A4 and removed the old not A4.
2016-02-04 HydraBus v1.0 Rev1_2 Release (CadSoft Eagle v7.1 files + BOM + Schematic + Gerber)
    [HydraBus_1_0_Rev1_2.GBL, HydraBus_1_0_Rev1_2.GBO, HydraBus_1_0_Rev1_2.GBP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]
2016-05-31 Add HydraBus_1_0_Shield_Template_Rev0 Kicad link
2016-12-06 HydraBus V1.0 Rev1.2+
    [HydraBus_1_0_Rev1_2plus.GBL, HydraBus_1_0_Rev1_2plus.GBO, HydraBus_1_0_Rev1_2plus.GBP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]
2017-08-03 HydraBus V1.0 Rev1.3
    [HydraBus_1_0_Rev1_3.GBL, HydraBus_1_0_Rev1_3.GBO, HydraBus_1_0_Rev1_3.GBP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]
2018-12-29 Updated pin assignment diagrams
2018-12-29 Removed GND/VCC arrows
2019-12-27 Updated 26 Dec 2019 with https://www.seeedstudio.com/opl.html
    [HydraBus_1_0_Rev1_3_BOM.xls]
2020-05-14 Import HydraBus v1.0 Rev1.4 done with KiCad (5.1.5)-2
    [HydraBus.kicad_pcb, HydraBus.sch, HydraBus_1_0_Rev1_4_BOM.xls]
2020-08-29 Update HydraBus_board.jpg with latest HydraBus v1.0 Rev1.4 board photo
2024-01-01 Add HydraBus v1.0 Rev1.5 Schematic/Board Hardware license CC BY-NC 4.0 (KiCad 6.0.11) Update HydraBus_1_0_HydraFW_Basic_PinAssignment & HydraBus_1_0_HydraFW_Default_PinAssignment_A4 with latest Hydra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
    [HydraBus.kicad_pcb, HydraBus.kicad_sch]
2024-01-01 Update README.md with pictures with latest HydraBus v1.0 Rev1.5 board (USB Type C)
2024-03-16 Add HydraBus_v1_0_Rev1_SoBv1_DP6037-Top_Bottom (Top is same as Bottom) in DXF & STL format
    [HydraBus_v1_0_Rev1_SoBv1_DP6037-Top_Bottom.dxf, HydraBus_v1_0_Rev1_SoBv1_DP6037-Top_Bottom.stl]
